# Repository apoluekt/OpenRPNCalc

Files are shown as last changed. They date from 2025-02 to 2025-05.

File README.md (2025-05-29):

# OpenRPNCalc
Open-source and open-hardware scientific RPN calculator

## Introduction

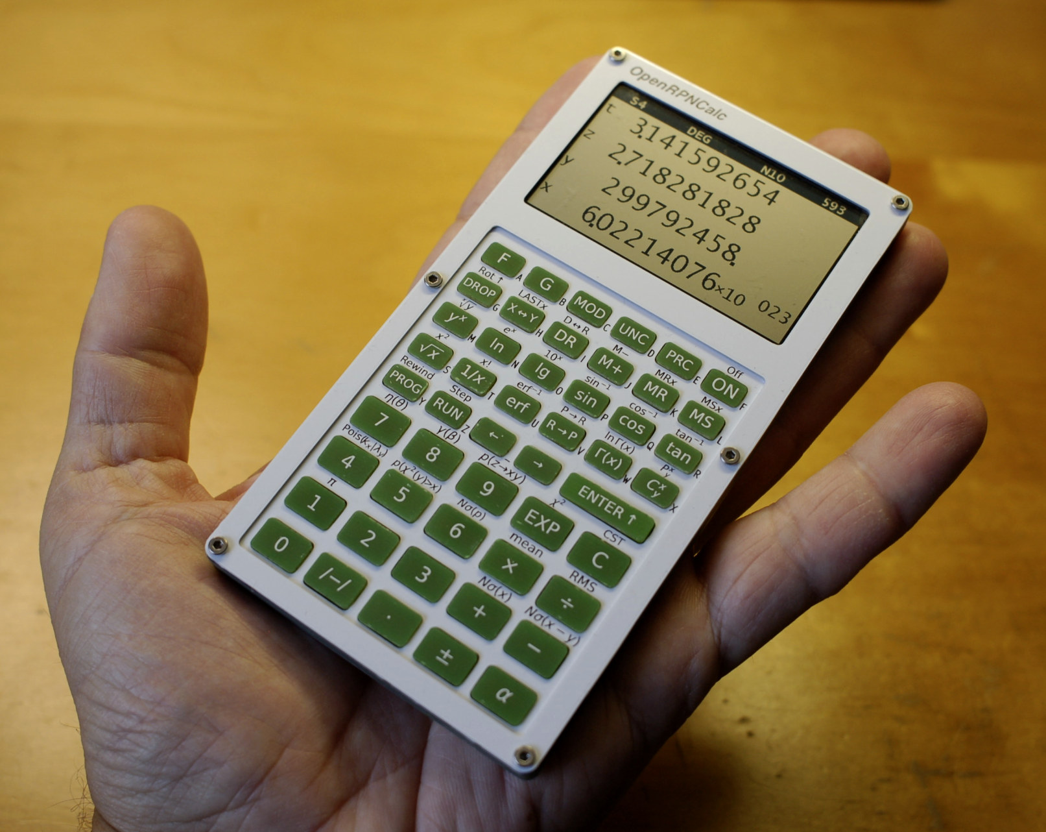
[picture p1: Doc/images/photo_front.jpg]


OpenRPNCalc is a scientific calculator based on the STM32 microcontroller. Its source code, schematics, and PCB design files are released under an open license. The goal is to develop a hardware platform with the following features: 
  * Reproducible without special tools, using only boards produced by PCB prototyping services
  * A customizable keyboard to accommodate specific needs (such as RPN or algebraic logic, custom functions)
  * Low power consumption and long battery life
  * A high-quality, compact and sturdy enclosure

The hardware is inspired by the [SwissMicros](https://www.swissmicros.com/products) calculators, but is designed from scratch. The calculator features: 

  * [Reverse Polish notation](https://www.hpmuseum.org/rpn.htm) with a large stack (up to 100 elements)
  * Double-precision arithmetic
  * "Standard" scientific calculator functions (trigonometric, logarithms, exponentiation, square root and power)
  * Error function (erf) and its inverse (erfinv), Gamma and log(Gamma) functions, combinations and permutations, p-values for Poisson, Gaussian, and chi-squared distributions
  * Fixed, scientific (SCI) and engineering (ENG) display modes (including SI prefixes in ENG mode), with adjustable precision from 3 to 10 digits
  * Calculations with uncertainties using error propagation (UNCERT mode) - a feature rarely found in software calculators and almost unheard of in hardware calculators
  * Formulas from relativistic kinematics (centre-of-mass two-body decay momentum, conversion between angle and pseudorapidity, beta and gamma factors)
  * Statistical functions: mean (or weighted mean in UNCERT mode), RMS, chi-squared of a series of values (only in UNCERT mode). 
  * 100 memory registers
  * Power consumption: 0.6mA running at 16MHz, 16 uA in standby mode with the LCD on, and 5 uA with the LCD off.
  * Optional HP48 keyboard files, with the aim to run [DB48x](https://48calc.org/) (this is still very much WIP)

## Hardware overview

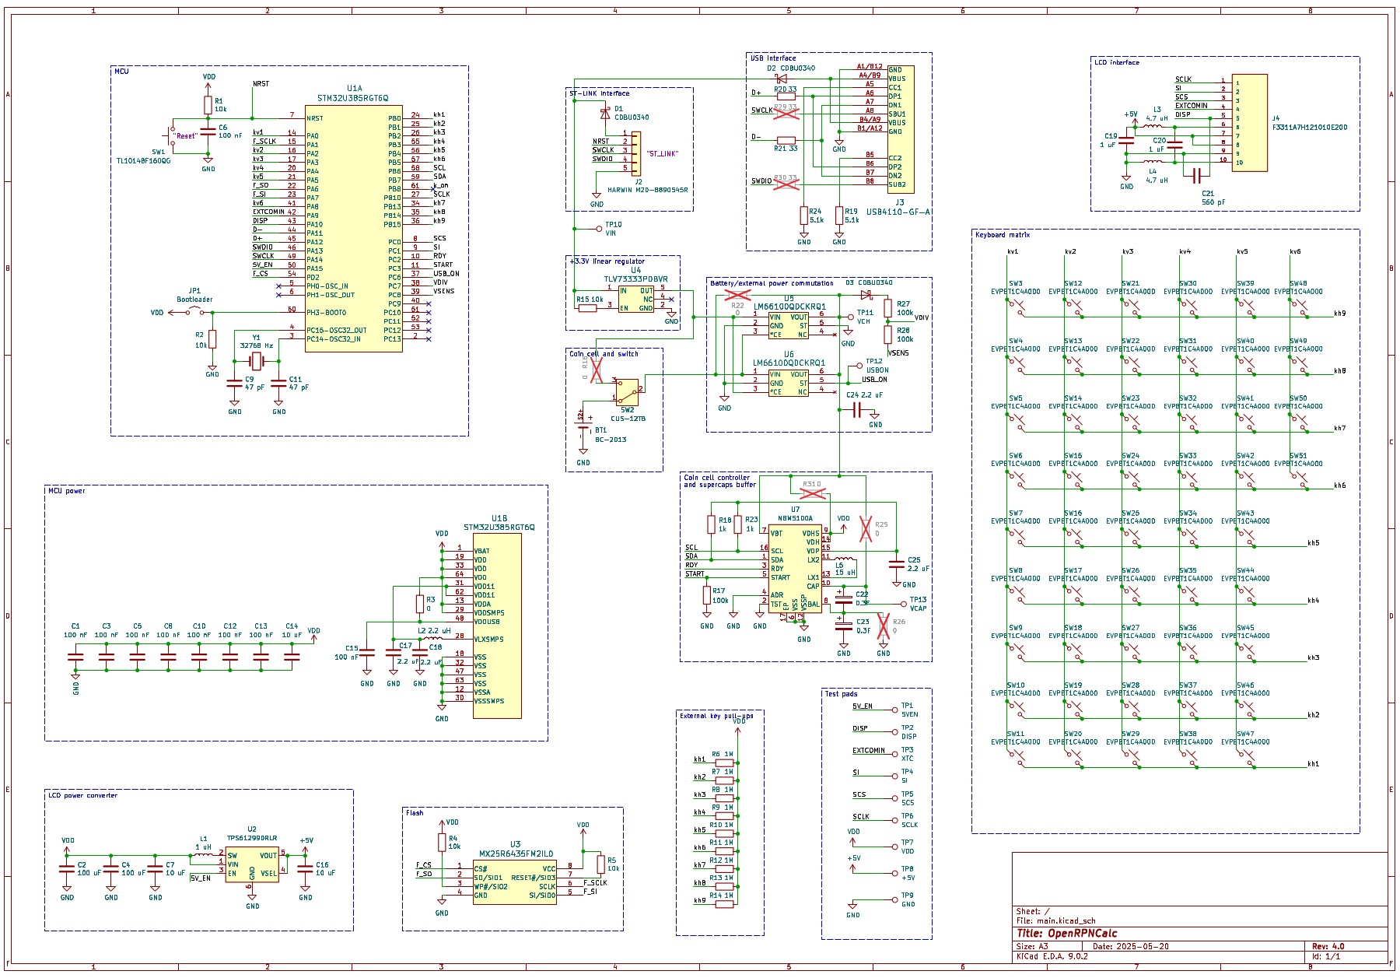
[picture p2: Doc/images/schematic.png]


The calculator is built around a low-power 32-bit ARM microcontroller, the [STM32U385](https://www.st.com/en/microcontrollers-microprocessors/stm32u385rg.html). The display is a Sharp memory LCD module, the [LS027B7DH01](https://www.sharpsde.com/products/displays/model/LS027B7DH01/) (400x240 pixel monochrome). The keyboard uses light-touch tactile switches, specifically the Panasonic [EVPBT1C4A000](https://industry.panasonic.com/global/en/products/control/switch/light-touch/number/evpbt1c4a000) (50g actuation force). All electronics are powered by a 3V lithium battery (CR2032), which should be sufficient for several years of operation. 

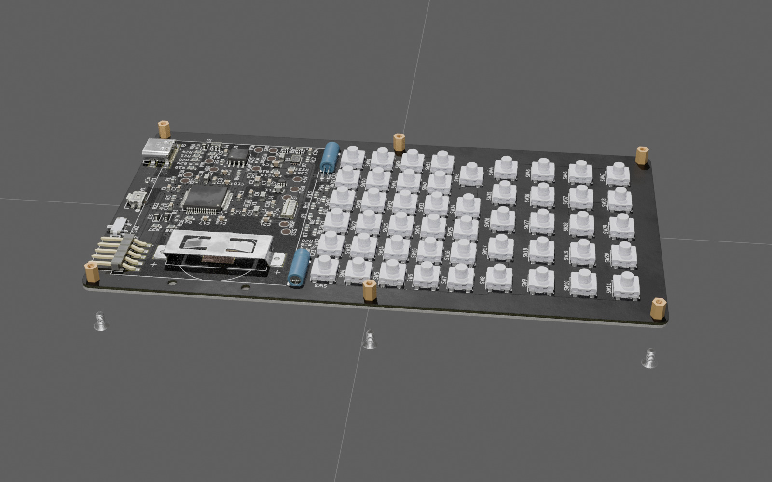
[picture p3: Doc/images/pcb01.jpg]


The enclosure is designed as a stack of multiple PCBs. The front and back panels are aluminium PCBs with a white solder mask and black silkscreen. The keys are also made of PCB, with labels printed as silkscreen. All components are kept together with six M2 standoffs and twelve flat-head screws. The enclosure dimensions are 139 x 73 x 8 mm. 

## Repository contents

   * [Code](Code): STM32 firmware developed using STM32Cube IDE
   * [Hardware](Hardware): Schematic and PCB design files for KiCad, PCB production files
   * [Doc](Doc): Documentation and images
   * [Emulator](Emulator): Online emulator files to be deployed to github-pages or other web hosting

## Documentation

   * [Schematics and parts](Doc/schematics.md) of the PCBs and the list of electronic components and other parts with links to datasheets
   * [PCB design](Doc/pcb_design.md): images of the PCB layers and their functions
   * [Case and keyboard assembly](Doc/assembly.md): photos of the insides of the calculator, assembly instructions
   * [Firmware](Code/README.md): code structure and flashing instructions

## Emulator 

[Online emulator](https://apoluekt.github.io/OpenRPNCalc/Emulator/), based on the original calculator firmware extended with Emscripten and Raylib

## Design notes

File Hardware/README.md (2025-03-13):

# Hardware design files

Contents of this folder: 

* [PCBs](PCBs): KiCad design files (schematic and PCBs) for all sevel layers. Where appropriate, Python files are also provided to produce silkscreen labels, place components, and make edge cuts.
* [production](production): Production files created in KiCad (Gerber files, bill of materials, position files for assembly service) for each of the 7 PCBs. These can normally be submitted to the PCB prototyping service without modifications.

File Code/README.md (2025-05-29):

# OpenRPNCalc firmware

The code is developed with STM32CubeIDE (specifically, version 1.17 under Linux). 

To create the binary file to flash the STM32 chip, go to "Project/Properties/C/C++ Build/Settings" and under "MCU/MPU Post build outputs" check "Convert to a binary file (-O binary)". Then build the project ("Project/Build all") which will produce the file "Debug/OpenRPNCalc.bin". This is the binary that needs to be flashed. 

STM32U3 series is not yet supported by the `st-link` tools in Linux. Use proprietary STM32CubeProgrammer.

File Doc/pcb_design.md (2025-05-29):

# PCB design

The enclosure is constructed as a stack of PCBs without needing 3D-printed elements.

Aluminium back panel and main PCB. All the PCBs are held together by six 4mm-high M2 brass standoffs. 



1st 1.6mm-thick spacer added. The standoffs need to be small enough to fit into 3.4mm holes in the spacers. The first spacer has guides to precisely position the keyboard switches while soldering. 

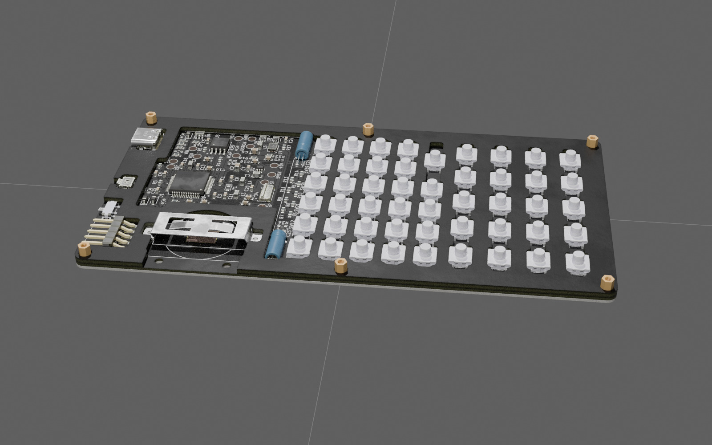
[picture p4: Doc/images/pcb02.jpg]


After adding the 2nd 1.6mm spacer. It covers most of the components on the main PCB and serves as a support for the LCD. 

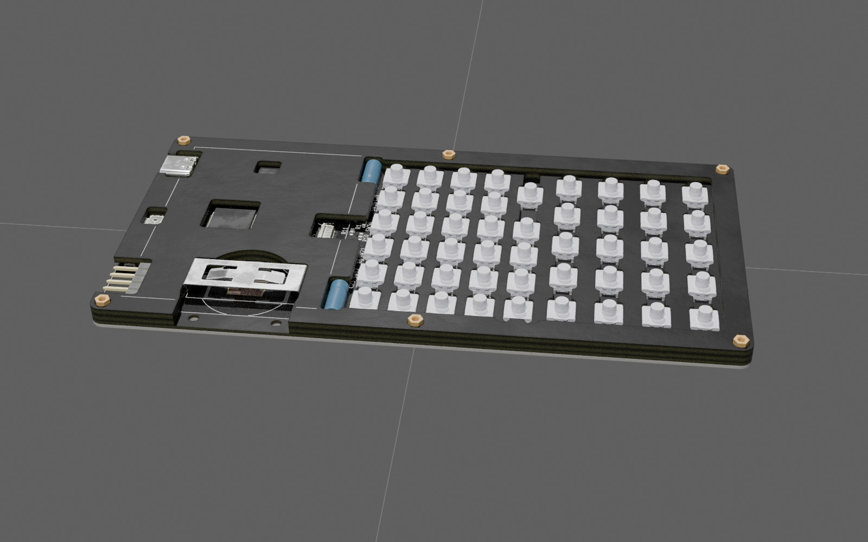
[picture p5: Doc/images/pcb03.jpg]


The CR2032 battery is installed in a slot that allows changing it without taking the full housing apart. The slot is made of two 1.6mm PCBs held by two M2 screws and nuts. To allow the slot to be inserted in the battery holder together with the battery, a wider bracket for the CR2430 battery is used instead of the CR2032 one. 

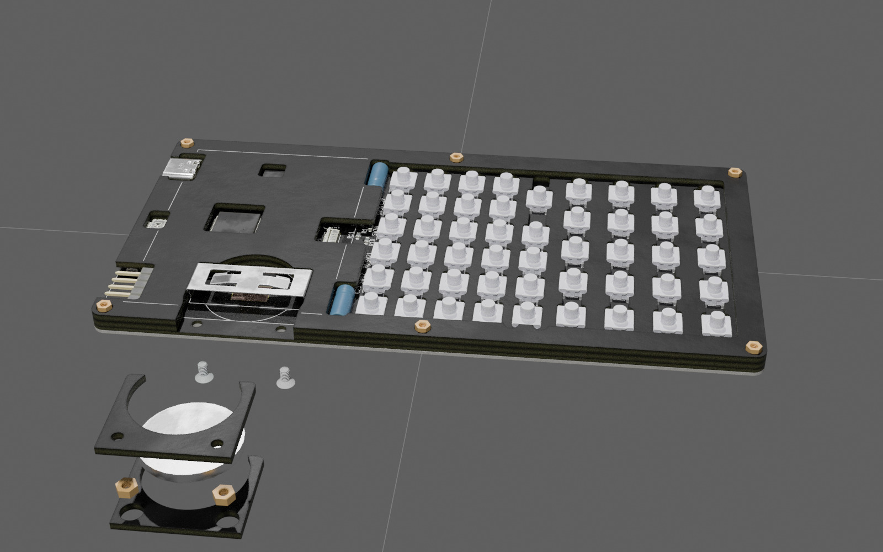
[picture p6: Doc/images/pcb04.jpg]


Battery slot installed in place. 

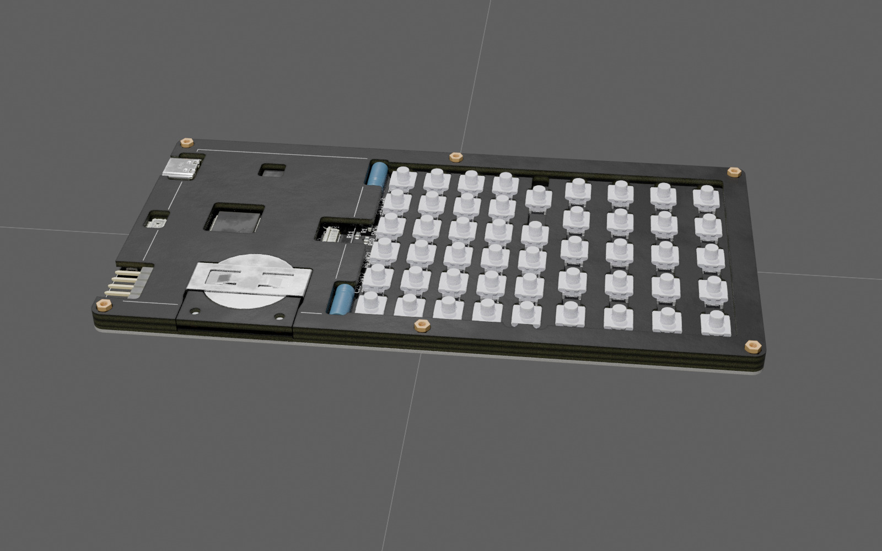
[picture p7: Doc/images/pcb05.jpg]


LCD connected. One needs to place an elastic (rubber) sheet of ~0.3mm thickness under the LCD such that it lies flat with the safe gap over the battery holder bracket. 

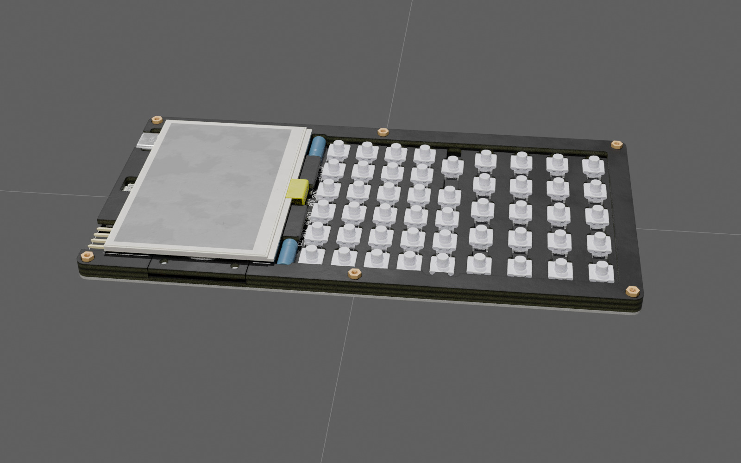
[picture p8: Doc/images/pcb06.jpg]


The 3rd 1.6mm spacer positions the LCD. 

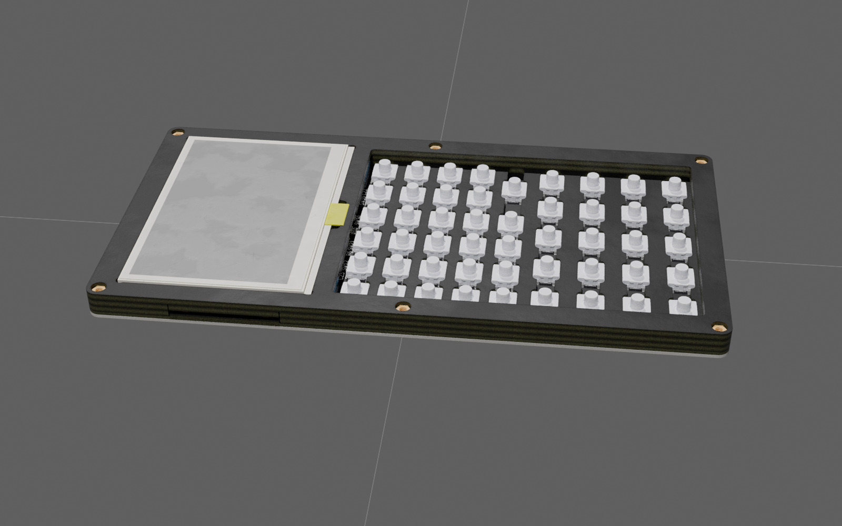
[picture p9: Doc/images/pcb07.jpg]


Keys are made of two parts soldered together: 1.6mm-thick top part with labels (with the solder pad on the bottom) and 0.8mm-thick bottom pad with plated through holes for soldering and 3mm diameter centre hole to put it tightly on the stem of the button switch. The wide "Enter" key has a thicker 1.2mm pad and a stabiliser that is hinged on the opposite side of the enclosure. 

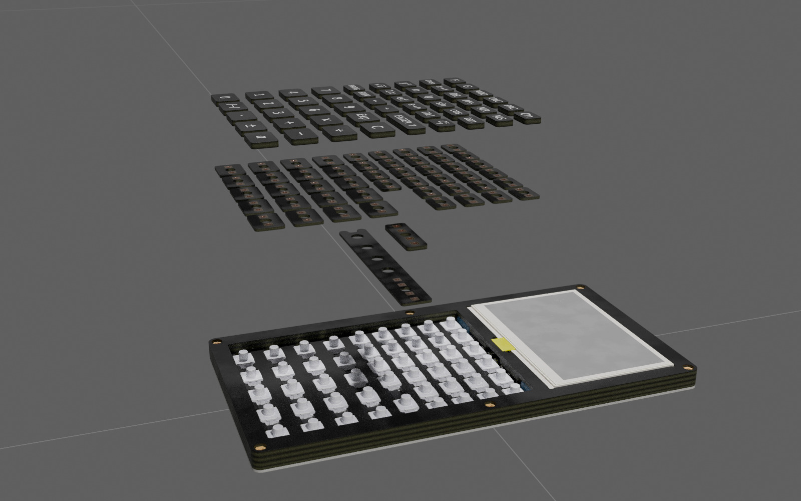
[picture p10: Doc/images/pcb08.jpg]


Wide "Enter" stabiliser and bottom pad put in place (in reality, it will also have the top part soldered at this stage). 

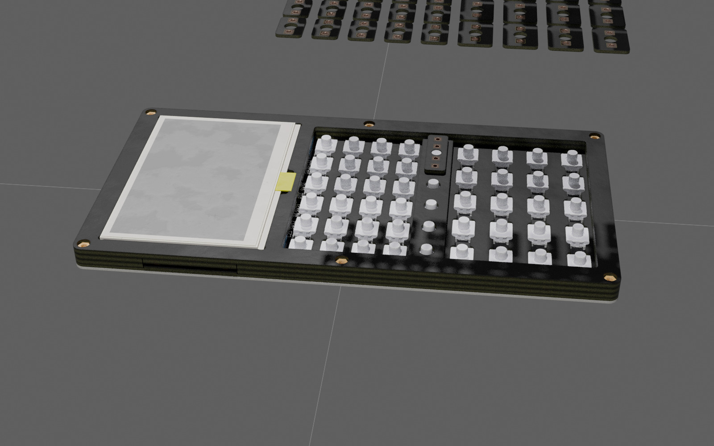
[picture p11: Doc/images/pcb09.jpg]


All keys put in place. 

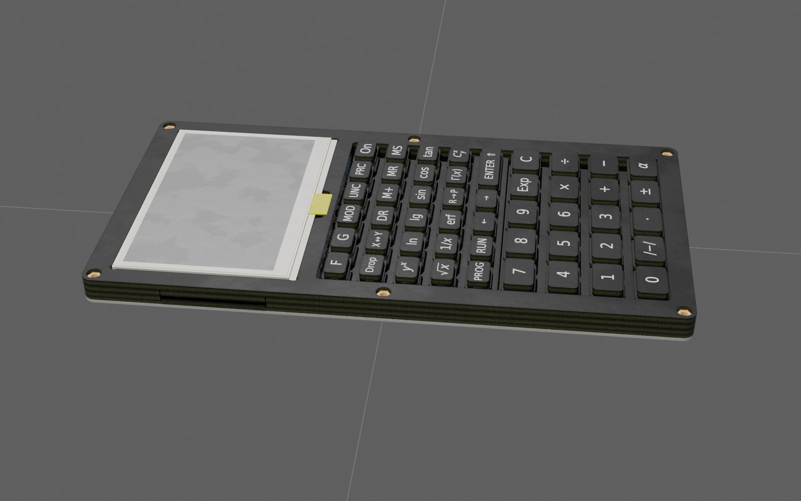
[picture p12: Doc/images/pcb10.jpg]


The front panel with labels and the frame that holds the LCD are held by six screws. 

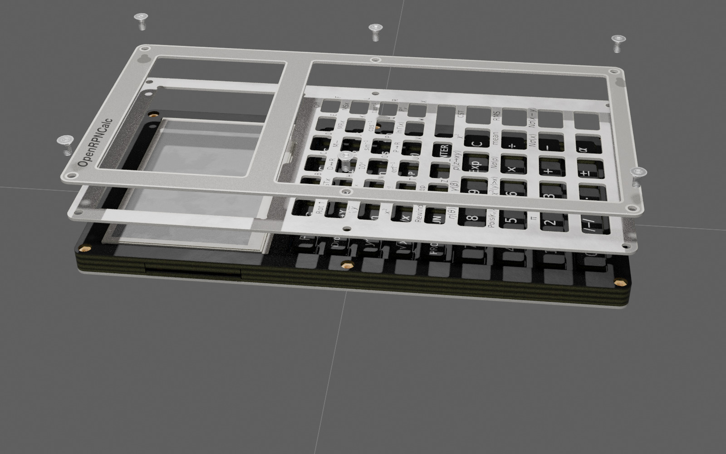
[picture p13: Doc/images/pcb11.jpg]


The calculator fully assembled. 

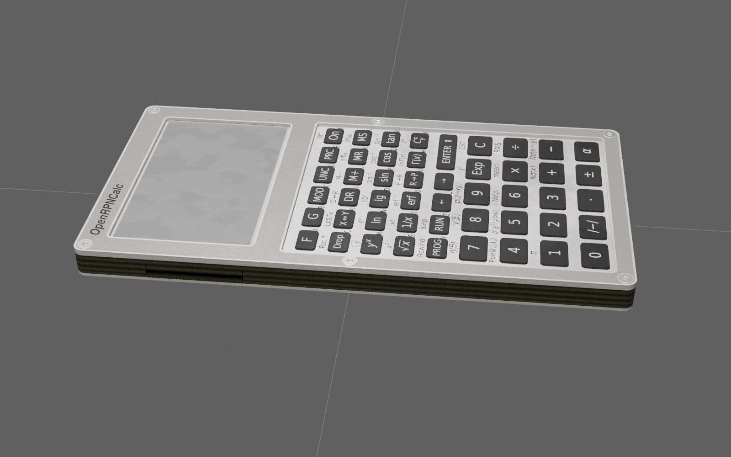
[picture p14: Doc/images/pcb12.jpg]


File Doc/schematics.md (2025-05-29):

# Schematics and parts

Rev. 4 uses a single PCB for the MCU and keyboard



## Notes 

### MCU

* The most recent STM32U385 is used here (256kB RAM, 1MB flash, ultra-low power with only 10 uA/MHz consumption)
* JP1 must be shorted to enter the USB bootloader for the fresh (or bricked) chip. 

### MCU power

* MCU is powered by the internal SMPS supply to ensure maximum power efficiency. The relevant external elements are L2, C17, and C18.
* R3, C15 are needed only if the USB interface is used. Otherwise, VDDUSB can be pulled to ground (?)

### LCD power converter

* This circuit is needed to provide +5V for the LCD. The newer TPS61299 chip is used with only 95 nA quiescent current. The version with "true shutdown" mode is used here (i.e. +5V rail is grounded when 5V_EN signal is low). 

### Flash

* Low-power 8MB chip Macronix MX25R6435FM2IL0 in single SPI mode (faster quad SPI mode is not used). 

### LCD interface

* Standard circuitry from LS027b7DH01 datasheet.
* Note that since the LCD connector is positioned on the PCB side facing the LCD, and the flat cable is bent 180 degrees, we have to use the flat cable connector that has contacts on **top**. The part used here has contacts on both sides, but the most abundant connectors with only bottom contacts won't work! 

### USB interface

* USB-C connector in USB-2.0 mode.
* SBU1 and SBU2 contacts can optionally be connected to the ST-LINK interface lines by installing the bridges R29 and R30 (not populated by default). This should allow for using the [SWD over USB-C](https://hackaday.io/project/192857-swd-over-usb-type-c-new-way-of-programming-boards) programmer and debugger. 

### ST-LINK interface

* 2.5mm pitch connector. Can use either 5V or 3.3V (?) lines from the ST-LINK probe to power the calculator. 

### +3.3V linear regulator

* Simple LDO regulator that produces stabilised +3.3V from either USB or ST-LINK input.

### Coin cell and switch

* The power switch is installed to completely switch the power off without removing the battery. Normally, the MCU is always in the idle (STOP) mode waiting for the external interrupt, so operating the switch in normal operation is not needed. 

### Battery/external power commutation

* A pair of "ideal diodes" which take the power from the source with a higher voltage. The USB_ON signal tells the MCU that external power is connected.
* U5 and U6 are optional. Instead, one can install the bridges R22 and R16 to manually switch the power between the battery and external (USB/ST-LINK) sources. 
* D3, R27 and R28 make a switchable divider to measure the battery voltage when VSENS is pulled low. When VSENS is disconnected (most of the time), there is no current drain. One has to make sure that the MCU is operated at the voltage (VDD) not lower than the battery voltage, otherwise the current will flow via the internal protection diodes in the MCU. 

### Coin cell controller and supercaps buffer

* NBM5100A is the coin cell life booster with supercap buffer. It limits the maximal current drawn from the coin cell to a programmable value (can be as low as 2 mA), with the excess taken from the supercaps during periods of high power consumption. It also provides stabilised voltage to power the STM32 and other circuitry.
* NBM5100A is optional. Instead of installing it, together with the surrounding passive elements, one can install the brige R31 to directly connect the calculator circuit to the coin cell or external power. Possibly, one can also install one of the supercaps and add the bridge R26 (not two supercaps sequentially, due to the absence of balancing). Make sure the supercap can survive 3.3V input voltage in this case. 
* Output voltage for NBM5100A should be set to 3V to make sure that the switchable voltage divider (see above) works correctly. 

### External pull-ups

* 1M pull-ups are used instead of STM32 internal 40k pull-ups to limit the current draw when the keys are pressed.
* It seems that the input pin capacitance and parasitic capacitance of the keyboard traces are high enough that a quick scan of the keyboard matrix is impossible with such high-impedance pull-ups. Therefore, the firmware should use them only when waiting for an external interrupt in the idle mode (waiting for a key press event), but to do the keyboard scan to determine which key was pressed, one has to switch the internal pull-ups in addition. 

### Test pads

* LCD signals and voltages 

### Keyboard matrix

* No diodes are added, so only up to two simultaneous key presses can be registered without ghosting. 

## Parts and datasheets

Electronic components from the KiCAD BOM: 

| Quantity | Value/model | Package | Comment |
|-|-|-|-|
| 1	| [STM32U385RGT6Q](https://www.st.com/en/microcontrollers-microprocessors/stm32u385rg.html) | LQFP64 | Microcontroller | 
| 1	| [MX25R6435FM2IL0](https://www.macronix.com/Lists/Datasheet/Attachments/8868/MX25R6435F,%20Wide%20Range,%2064Mb,%20v1.6.pdf)	| SOP-8L | 8MB flash memory | 
| 1	| [Nexperia NBM5100A](https://www.nexperia.com/product/NBM5100ABQ) | DHVQFN-16 | Coin cell controller | 
| 1	| [TI TPS61299](https://www.ti.com/product/TPS61299)	| SOT-5X3 (DRL) | 5V step-up converter | 
| 1	| [TI TLV73333PDBVR](https://www.ti.com/product/TLV733P/part-details/TLV73333PDBVR) | SOT-23 (DBV0005A) | LDO voltage regulator | 
| 2	| [TI LM66100QDCKRQ1](https://www.ti.com/product/LM66100-Q1/part-details/LM66100QDCKRQ1) | SOT-SC70 (DCK0006A) | Ideal diode | 
| 1	| [TL1014BF160QG](https://www.e-switch.com/wp-content/uploads/2022/06/TL1014.pdf) | | Button switch |
| 49 | [Panasonic EVPBT1C4A000](https://industry.panasonic.com/global/en/products/control/switch/light-touch/number/evpbt1c4a000)	| | Button switch |
| 1	| [Nidec CUS-12TB](https://www.nidec-components.com/us/product/detail/00000195/) | | Slide switch | 
| 1	| [BC-2013](https://www.batteryholders.com/part.php?pn=BC-2013&original=&override=)	| | CR2430 coin cell battery holder |
| 1	| [HARWIN M20-8890545R](https://www.harwin.com/products/M20-8890545R) | | SMT pin header, 5 pins, 2.5mm pitch |
| 1	| [USB4110GFA](https://gct.co/connector/usb4110) | | USB-C connector | 
| 1	| [AMPHENOL F3311A7H121010E200](https://www.amphenol-cs.com/product/f3311a7h121010e200.html) | | Flat cable connector, 10 pins, 0.5mm pitch, top and bottom contacts | 
| 1	| 32768 Hz | 2012 | Quartz resonator | 
| 3	| CDBU0340	| 0603 | Schottky diode | 
| 1	| 1 uH | 0805 | Inductor | 
| 1	| 2.2 uH | 0805 | Inductor | 
| 2	| 4.7 uH | 0805 | Inductor | 
| 1	| 15 uH	| 0805 | Inductor | 
| 9	| 100 nF	| 0603 | Ceramic capacitor |
| 2	| 47 pF	| 0603 | Ceramic capacitor |
| 3	| 10 uF	| 0603 | Ceramic capacitor |
| 4	| 2.2 uF | 0603 | Ceramic capacitor |
| 2	| 1 uF | 0603 | Ceramic capacitor |
|	2 | 100 uF | 0805 | Ceramic capacitor |
| 1	| 560 pF | 0603 | Ceramic capacitor |
| 2	| 0.3F | 4x10mm | Supercapacitor | 
| 5	| 10k	| 0603 | Resistor | 
| 9	| 1M | 0603 | Resistor | 
| 3	| 100k | 0603 | Resistor | 
| 2	| 1k | 0603 | Resistor |
| 2	| 5.1k | 0603 | Resistor |
| 2	| 33 | 0603 | Resistor |
| 1	| 0	| 0603 | Resistor |

Other components

| Quantity | Part |  
| - | - |
| 1 | Sharp Memory LCD, model [LS027B7DH01](https://www.alldatasheet.com/datasheet-pdf/pdf/433405/SHARP/LS027B7DH01.html) |
| 1 | CR2032 coin cell battery | 
| 6 | M2 x 4mm brass standoff, Round or hex, should tightly fit into 3.4mm holes on the PCB | 
| 14 | M2 x 4mm screw | 
| 4-5 | M3 screw and nut for the keycap soldering jig | 
| 2 | M2 x 1.6mm hex nut |
| 1 | ST-LINK v2 programmer with 2.5mm pitch pin header cable | 
| 1 | USB-C cable |

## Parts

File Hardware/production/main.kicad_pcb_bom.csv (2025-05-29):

Designator | Quantity | Value | Footprint | Package | MPN | DNP | Mount_Type | PARTREV | STANDARD | MAXIMUM_PACKAGE_HEIGHT | MANUFACTURER | Description | Function
BT1 | 1 | BC-2013 | BAT_BC-2013 |  |  |  | smt | D | Manufacturer Recommendations | 2.28mm | MPD
C1, C10, C12, C13, C15, C3, C5, C6, C8 | 9 | 100 nF | C_0603_1608Metric_Pad1.08x0.95mm_HandSolder |  |  |  | smt |  |  |  |  | Unpolarized capacitor
C11, C9 | 2 | 47 pF | C_0603_1608Metric_Pad1.08x0.95mm_HandSolder |  |  |  | smt
C14, C16, C7 | 3 | 10 uF | C_0603_1608Metric_Pad1.08x0.95mm_HandSolder |  |  |  | smt
C17, C18, C24, C25 | 4 | 2.2 uF | C_0603_1608Metric_Pad1.08x0.95mm_HandSolder |  |  |  | smt |  |  |  |  | Unpolarized capacitor
C19, C20 | 2 | 1 uF | C_0603_1608Metric_Pad1.08x0.95mm_HandSolder |  |  |  | smt
C2, C4 | 2 | 100 uF | C_0805_2012Metric_Pad1.18x1.45mm_HandSolder |  |  |  | smt
C21 | 1 | 560 pF | C_0603_1608Metric_Pad1.08x0.95mm_HandSolder |  |  |  | smt
C22, C23 | 2 | 0.3F | Supercap_4x10 |  |  |  | smt |  |  |  |  | Polarized capacitor
D1, D2, D3 | 3 | NSR0340HT1G | D_0603_1608Metric_Pad1.05x0.95mm_HandSolder |  |  |  | smt
J2 | 1 | HARWIN M20-8890545R | HARWIN_M20-8890545R |  |  |  | smt |  |  |  |  |  | "ST_LINK"
J3 | 1 | USB4110-GF-A | GCT_USB4110GFA |  |  |  | smt
J4 | 1 | F3311A7H121010E200 | AMPHENOL_F3311A7H121010E200 |  |  |  | smt | A | Manufacturer Recommendations | 1.62 mm | Amphenol
JP1 | 1 | Bootloader | R_0603_1608Metric_Pad0.98x0.95mm_HandSolder |  |  |  | smt |  |  |  |  | Jumper, 2-pole, open
L1 | 1 | 1 uH | L_0805_2012Metric_Pad1.15x1.40mm_HandSolder |  |  |  | smt
L2 | 1 | 2.2 uH | L_0805_2012Metric_Pad1.05x1.20mm_HandSolder |  |  |  | smt |  |  |  |  | Inductor
L3, L4 | 2 | 4.7 uH | L_0805_2012Metric_Pad1.15x1.40mm_HandSolder |  |  |  | smt
L5 | 1 | 15 uH | L_0805_2012Metric_Pad1.05x1.20mm_HandSolder |  |  |  | smt |  |  |  |  | Inductor
R1, R15, R2, R4, R5 | 5 | 10k | R_0603_1608Metric_Pad0.98x0.95mm_HandSolder |  |  |  | smt
R10, R11, R12, R13, R14, R6, R7, R8, R9 | 9 | 1M | R_0603_1608Metric_Pad0.98x0.95mm_HandSolder |  |  |  | smt
R17, R27, R28 | 3 | 100k | R_0603_1608Metric_Pad0.98x0.95mm_HandSolder |  |  |  | smt |  |  |  |  | Resistor
R18, R23 | 2 | 1k | R_0603_1608Metric_Pad0.98x0.95mm_HandSolder |  |  |  | smt |  |  |  |  | Resistor
R19, R24 | 2 | 5.1k | R_0603_1608Metric_Pad0.98x0.95mm_HandSolder |  |  |  | smt |  |  |  |  | Resistor
R20, R21 | 2 | 33 | R_0603_1608Metric_Pad0.98x0.95mm_HandSolder |  |  |  | smt |  |  |  |  | Resistor
R3 | 1 | 0 | R_0603_1608Metric_Pad0.98x0.95mm_HandSolder |  |  |  | smt |  |  |  |  | Resistor
SW1 | 1 | TL1014BF160QG | TL1014BF160QG_EWI |  |  |  | smt |  |  |  |  |  | "Reset"
SW10, SW11, SW12, SW13, SW14, SW15, SW16, SW17, SW18, SW19, SW20, SW21, SW22, SW23, SW24, SW25, SW26, SW27, SW28, SW29, SW3, SW30, SW31, SW32, SW33, SW34, SW35, SW36, SW37, SW38, SW39, SW4, SW40, SW41, SW42, SW43, SW44, SW45, SW46, SW47, SW48, SW49, SW5, SW50, SW51, SW6, SW7, SW8, SW9 | 49 | EVPBT1C4A000 | SW_SPST_EVQQ2 |  |  |  | smt
SW2 | 1 | CUS-12TB | CUS-12TB_NDC |  |  |  | smt
TP1 | 1 | 5VEN | TestPoint_Pad_D2.0mm |  |  |  | tht
TP10 | 1 | VIN | TestPoint_Pad_D2.0mm |  |  |  | tht
TP11 | 1 | VCH | TestPoint_Pad_D2.0mm |  |  |  | tht
TP12 | 1 | USBON | TestPoint_Pad_D2.0mm |  |  |  | tht
TP13 | 1 | VCAP | TestPoint_Pad_D2.0mm |  |  |  | tht
TP2 | 1 | DISP | TestPoint_Pad_D2.0mm |  |  |  | tht
TP3 | 1 | XTC | TestPoint_Pad_D2.0mm |  |  |  | tht
TP4 | 1 | SI | TestPoint_Pad_D2.0mm |  |  |  | tht
TP5 | 1 | SCS | TestPoint_Pad_D2.0mm |  |  |  | tht
TP6 | 1 | SCLK | TestPoint_Pad_D2.0mm |  |  |  | tht
TP7 | 1 | VDD | TestPoint_Pad_D2.0mm |  |  |  | tht
TP8 | 1 | +5V | TestPoint_Pad_D2.0mm |  |  |  | tht
TP9 | 1 | GND | TestPoint_Pad_D2.0mm |  |  |  | tht
U1 | 1 | STM32U385RGT6Q | LQFP64_STM |  |  |  | smt
U2 | 1 | TPS61299DRLR | SOT-563 |  |  |  | smt
U3 | 1 | MX25R6435FM2IL0 | SOP_8L_200_MAC |  |  |  | smt
U4 | 1 | TLV73333PDBVR | DBV0005A_N |  |  |  | smt
U5, U6 | 2 | LM66100QDCKRQ1 | SC70-6_DCK_TEX |  |  |  | smt
U7 | 1 | NBM5100A | DHVQFN-16-1EP_2.5x3.5mm_P0.5mm_EP1x2mm |  |  |  | smt |  |  |  |  | coin cell booster charge pump DHVQFN16 SOT763
Y1 | 1 | 32768 Hz | Crystal_SMD_2012-2Pin_2.0x1.2mm_HandSoldering |  |  |  | smt

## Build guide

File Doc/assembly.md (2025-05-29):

# Assembly

PCBs as they come from the prototyping service. The white ones are aluminium-based (black silkscreen on white mask), and the others are the usual FR4 (white silkscreen on black mask or green mask in the case of keycaps). 
The Alu PCBs are used as they are, while the FR4 PCBs contain panelised keycaps (the green board), parts of the jig to help solder the keys (denoted A, B, and C) and battery slot layers (3rd PCB in the top row) that have to be separated from the frames before assembling the enclosure. 

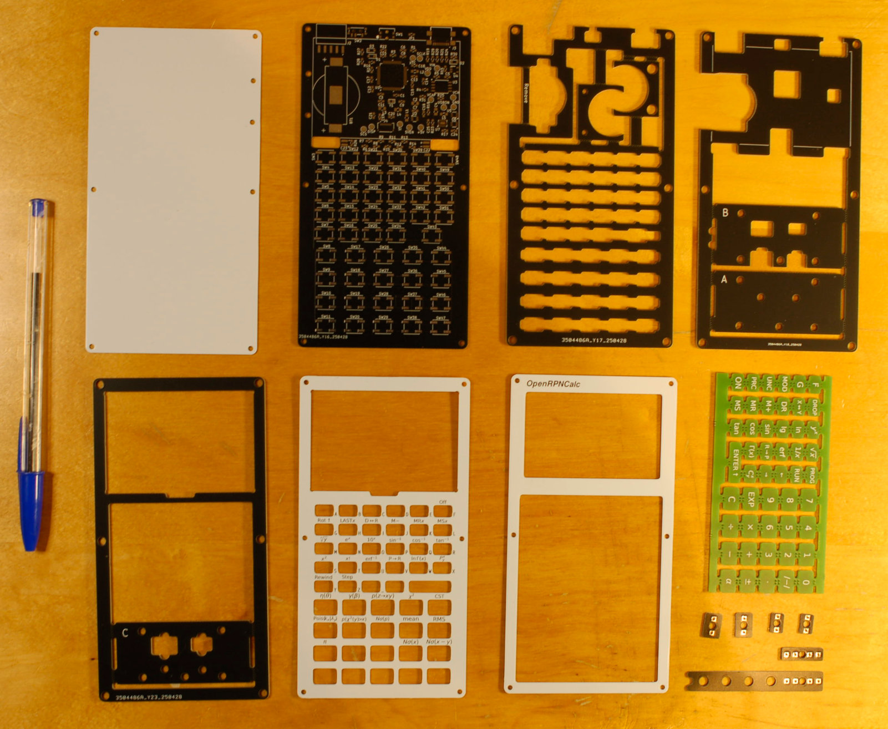
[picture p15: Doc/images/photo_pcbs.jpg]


The soldering jig assembled. It's made as a stack of three 1.6mm-thick boards (denoted from bottom to top A, B, and C) kept together with M3 screws and nuts. The two slots on the edge are used to hold the top parts of the keycaps while finishing them with the file to remove "mouse bites" traces, while the two slots on the top side are used to precisely position the top and the bottom parts of the keycap while soldering them together. 

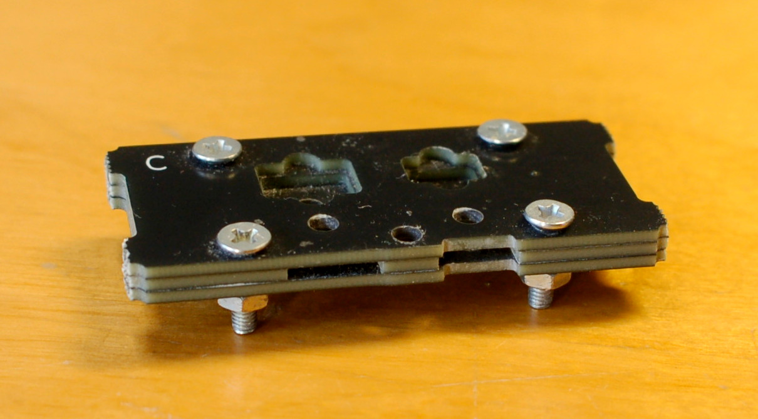
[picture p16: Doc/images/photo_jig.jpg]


Soldered keycaps after cleaning with isopropanol. 

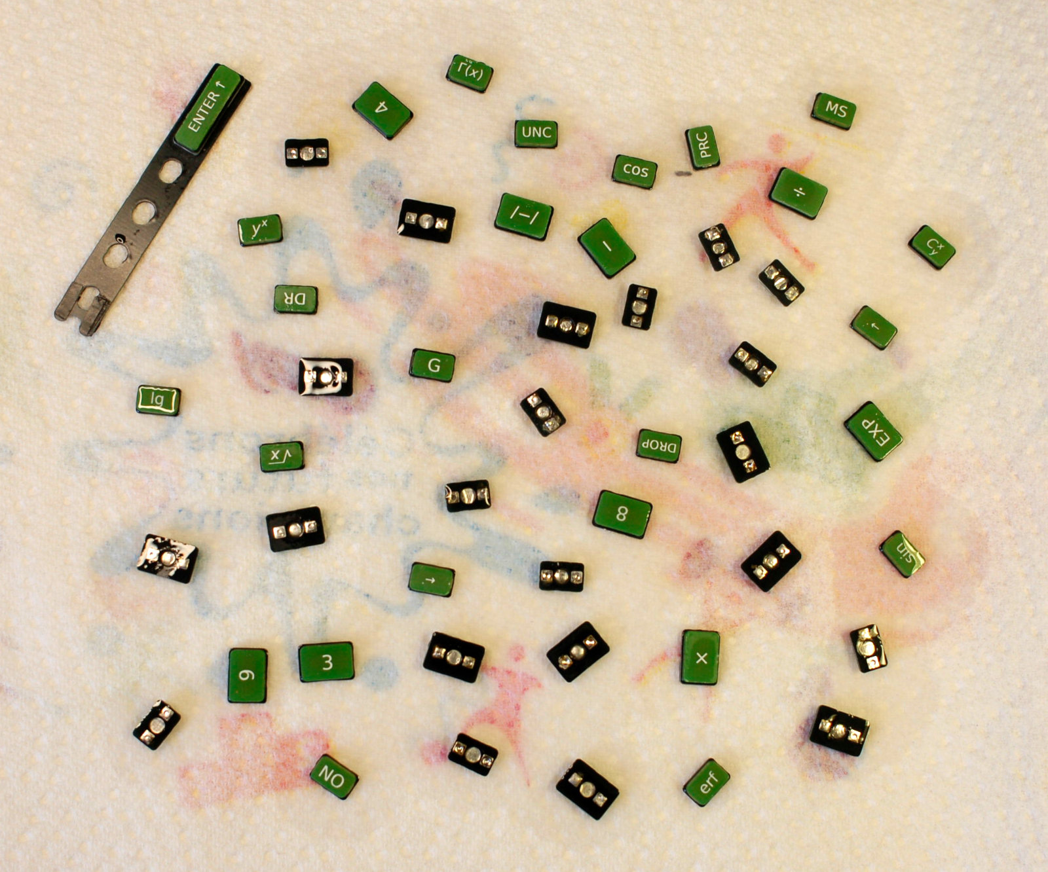
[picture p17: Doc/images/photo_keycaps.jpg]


The main PCB (without soldering the electronic components) with Spacer 1 on top, battery holder and slot with the CR2032 battery, Enter key with its stabiliser and a couple of other keys. 

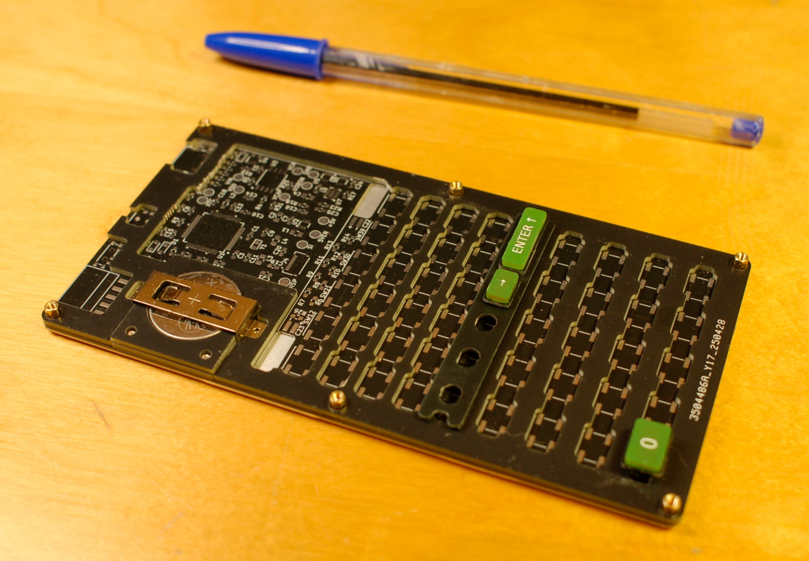
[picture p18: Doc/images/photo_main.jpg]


The main PCB with components soldered and Spacer 1 placed on top. The spacer has "rails" to precisely position the button switches for manual soldering. 

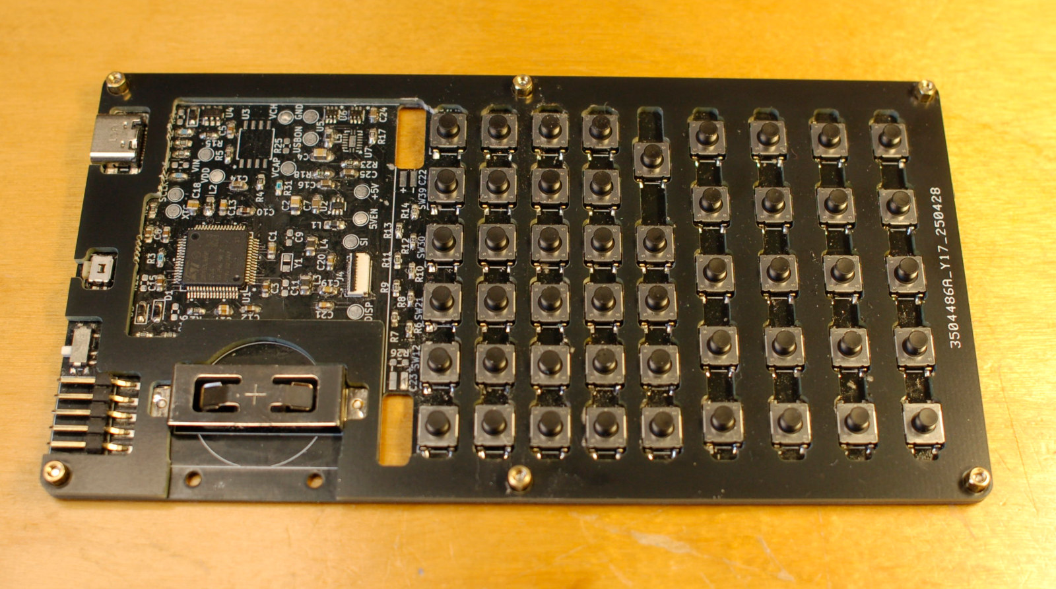
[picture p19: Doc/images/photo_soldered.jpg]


Closeup view of the (from left to right) USB-C connector, Reset switch, power switch and ST-LINK connector. 

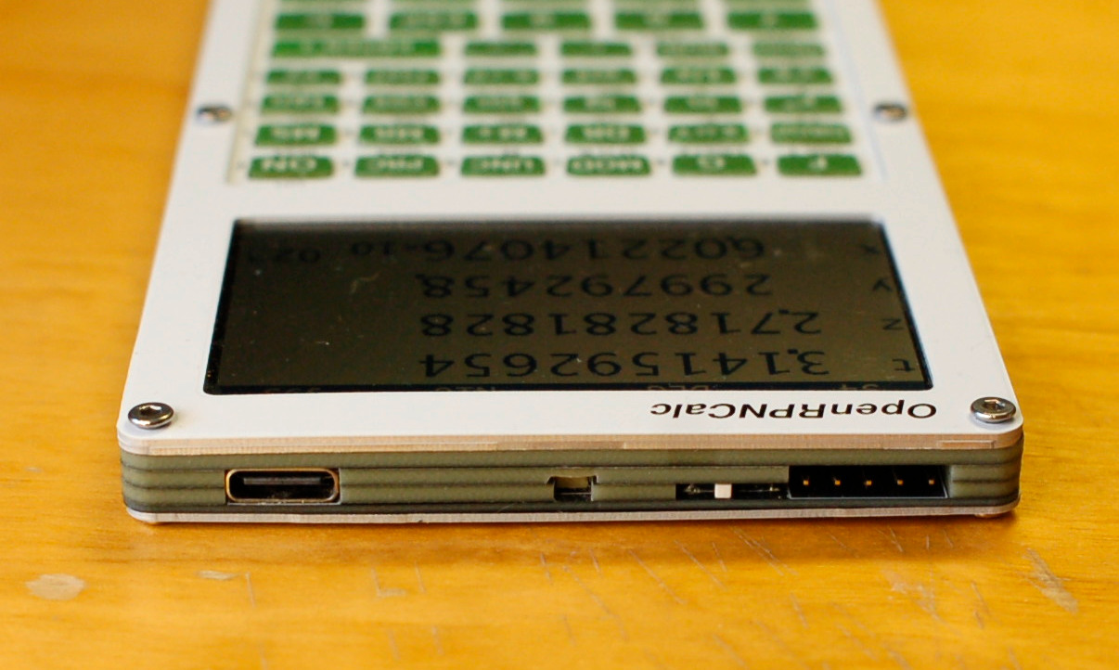
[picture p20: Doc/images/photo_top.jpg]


Fully assembled calculator 



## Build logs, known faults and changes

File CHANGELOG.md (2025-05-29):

# Changelog

## 29/05/2025 
  * Updated firmware to be used with STM32U385 MCU. For now, minimal changes wrt. rev3.1:
    * Remap keys to the new 49-key layout
    * Update pinout to the new hardware
    * Small updates related to the modifications in HAL (EXTI callbacks)
    * Battery voltage measurement still has issues, showing raw ADC reading instead of volts. 

## 20/05/2025.
  * Bug fixes to Rev 4: 
    * Spacer2: Adjusted key soldering jig; increased gap between the battery holder and the spacer
    * EnterStab: Adjusted hole positions
    * Main: Corrected footprints for TPS61299 and diodes
  * Added HP48 keyboard layout in addition to the custom one: 
    * PCBs in Hardware/PCBs with _hp48 suffix
    * production files in Hardware/production with _hp48 suffix

## 27/04/2025. Revision 4
  * Hardware modifications in Rev 4:
    * [STM32U385](https://www.st.com/en/microcontrollers-microprocessors/stm32u385rg.html) processor
    * Added USB interface (USB-C connector) with optional support of [SWD over USB-C](https://hackaday.io/project/192857-swd-over-usb-type-c-new-way-of-programming-boards)
    * Added external flash ([Macronix MX25R6435F](https://www.macronix.com/Lists/Datasheet/Attachments/8868/MX25R6435F,%20Wide%20Range,%2064Mb,%20v1.6.pdf), 8Mbytes)
    * Added coin cell booster with supercaps buffer ([Nexperia NBM5100A](https://www.nexperia.com/product/NBM5100ABQ) and 2x0.3F caps)
    * New 5V booster for LCD ([TPS61299](https://www.ti.com/product/TPS61299))
    * External/battery voltage commutation with a pair of "ideal diodes" ([LM66100-Q1](https://www.ti.com/product/LM66100-Q1))
    * Keyboard layout modifications: additional row of function keys, wide "Enter"
    * Different model of tactile switches (Panasonic EVP-BT1C4A000) to avoid 3D-printed pads for the keys
    * CR2032 coin cell by default

## 28/03/2025
  * Firmware: 
    * Rudimentary programming capability: record up to 100 operations and run the recorded sequence either all at once or step-by-step. 
      No loops or branching.
    * Increase delays in keyboard scan for stability with high-impedance pull-ups
    * Speed up LCD output
    * Independent setting of precision (number of significant digits) for NORMAL and UNCERT contexts
  * Hardware: 
    * Updated front panel labels to reflect the firmware update (added programming functions).

## 07/03/2025
  * Hardware: Rev. 3 of the schematics and enclosure. 
  * Firmware:
    * 100 memory registers accessible via F-RCL and F-STO functions, with the address of the memory register passed in the X register of the stack
    * Changes for Rev. 3 of hardware (upright LCD screen instead of upside-down in the old revisions; external pull-ups for key matrix)
    * Enscripten/raylib code for the online emulator

## 20/02/2025
  * "Infinite" stack (HP48-like) instead of the fixed 4-element one (HP42-like). Practically, it's now limited to 100 elements,
    outght to be enough for anybody, and can be extended. 
  * Statistical functions (chi2 and mean for now) work with all the elements of the stack. 
  * Small bug fixes in the stack behaviour. 

## 14/02/2025 
  * New functions: 
    - Chi2, mean and RMS of values in the stack with uncertainties (work only in UNCERT) mode
    - Factorial
  * Keyboard scan fully interrupt-driven (entering STOP even when waiting for key release) and a few bugfixes 
    to improve keyboard response

## 01/01/2025
  * Working on Rev. 2 of OpenRPNCalc. Changes in firmware, enclosure and PCB design, mostly the same schematics. 
  * Changes in firmware:
    - Improvements in the alignment of the display elements and status bar.
    - Added cursor to highlight input elements (value or uncertainty, mantissa or exponent).
    - Removed the unnecessary delay loop in the initialisation phase.
  * Major change in the enclosure design:
    - The idea is to make an enclosure as a sandwich of PCBs rather than the 3d-printed one
    - More reliable silkscreen labels instead of printed stickers
    - Keyboard with PCB-based keys and pin header "pivots" (preliminary design for now, waiting for the PCBs to arrive)

## 25/06/2021
  * Added ROT-Up and ROT-Down functions ("F"+"Drop" and "G"+"Drop"): stack rotation in two directions
  * Added uncertainties for Y^X and ROOT(Y, X) functions

## 21/06/2021 
  * Added Poisson PDF ("F"+"4") and chi-squared tail probability ("F"+"5") functions

## 19/06/2021
  * Small fixes in schematics to reflect what is actually implemented in hardware. 
  * Put STM32 to STOP2 mode instead of STOP1 during standby. This reduces the current 
    consumed from battery to 2-3 uA with LCD off and 10-12 uA with LCD on
    (was 40 and 55 uA, respectively, with STOP1). 
  * Add new photos of the keyboard. 
  * Add links to datasheets in Doc/schematics.md

## 02/06/2021
  * Added C(n,k), P(n,k) functions calculated using log(Gamma) formula. 
    No check is done that arguments are positive, integer, etc.
  * Added significance (Nsigma(x), Nsigma(x-y)) functions. Work only in 
    UNCERT context. 

## 28/05/2021
  * Added relativistic kinematics functions (uncertainties are not implemented yet for them): 
    * Conversion between angle and pseudorapidity (eta <-> theta)
    * Conversion between beta and gamma factors (gamma <-> beta)
    * Center-of-mass momentum for 2-body decay (P(z->xy))
  * Gamma and log Gamma functions. 
  * Conversion between degrees and radians. 
  * Slight reshuffle of function keys. 
  * Update with ST-Link is now activated with "SHIFT+Reset" (instead of "ON+Reset").

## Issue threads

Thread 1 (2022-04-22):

Best calculator ever!

BasilioPV, 2022-04-22:
Thanks for sharing this awesome project to the community. I always dreamed with a calculator with the power of an Casio FX 991 but with the size of 80's Casio pocket models (which includes a plastic wallet and fit in the shirt pocket).

This project open the eyes for me: small size and simple electronics, ultra low power consumption (can be powered by solar cell) and very powerful.

I have some questions for you:
How do you produce the PCB including soldering components?
How can I purchase all components?

BasilioPV, 2025-03-17:
What PCB prototyping service do you use? Thanks very much for this project!

apoluekt, 2025-03-17:
Any cheap service that is able to do single-sided Alu PCBs and 0.8mm FR4. I've used JLCPCB, but see the caveat [here](https://www.hpmuseum.org/forum/thread-23291-post-201204.html#pid201204). For the PCB with the labels, you might want to use the service with a more transparent pricing policy, such as Aisler.

randy197, 2025-06-05:
Thanks @jcard0na , sorry I missed this in the discussions.

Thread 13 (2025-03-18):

LCD Availability

randy197, 2025-03-18:
Hi Anton, this project made my day when I found it. I immediately started collecting the BOM but have found the Sharp LCD you have used is VERY hard to come by from official sources.

Are there plans to use a different LCD in future? Or do you have any alternative suggestions? I have placed an order for a AliExpress 'version'. Will see how good the quality is. An AliExpress reviewer noted his LCD had a much higher power consumption compared to the genuine.

apoluekt, 2025-03-18:
Indeed, finding the Sharp screen is annoyingly hard, and your best bet is to go to AliExpress. It seems the cheapest sellers may sell the screens that are faulty in some way, so I'd try the more reputable ones.

The problem is any other LCD available at e.g. DigiKey is a sort of compromise in terms of quality, thickness, etc. I'd need to investigate, but a few years ago there really was no other option. If you find something competitive, let me know.

randy197, 2025-03-18:
Thanks for the reply. When it arrives I'll post back here on the quality. Could potentially start a catalogue of sellers which have decent screens.

I really appreciate you making this open. I've been wanting a physical calculator on my desk for years. Any decent RPN calc is worth hundreds these days so couldn't justify that, this is exactly what I was looking for.

apoluekt, 2025-03-18:
Thanks, keep me posted how it goes, and be ready that it will require some tweaking, especially the keyboard part. I've slightly changed the design of the keycaps to remove the 3D-printed pads, and switched to the Panasonic switches with longer stems in the current version, but I haven't actually tested this myself yet.

Also have a look at https://github.com/apoluekt/OpenRPNCalc/issues/1 concerning possible issue with PCB proto service when submitting the keyboard PCB

apoluekt, 2025-04-21:
Apparently, DigiKey has a stock of Sharp screens now, although at a higher price than AliExpress. https://www.digikey.fr/en/products/detail/sharp-microelectronics/LS027B7DH01/5054066

Closed 2025-03-18.

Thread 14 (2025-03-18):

Support for DB48x

c3d, 2025-03-18:
I wonder if this would be a good platform for [DB48x](https://github.com/c3d/db48x/tree/stable), a modern implementation of RPL. At first sight, the chosen CPU is a bit small (1M of Flash, IIRC?)

Based on your experience, how difficult would it be to:
1. Add a row of keys, in order to be able to match the HP48 or HP50 keyboard layout? The schematic seems to indicate that you use all the pins on the connector, but one of them is labeled as "x".
2. Add a wide ENTER key (the thin ENTER key is considered a major downside of the HP50G)
3. Add a USB connector in addition/replacement of the ST-LINK

Just questions.

apoluekt, 2025-03-18:
I haven't looked closely to the DB48x h/w requirements, but I suspect it might require using a more powerful MCU, and possibly an external flash if it makes use of a file system. I'm considering eventually moving to the STM32U series of processors, a more performant and power-efficient option. Maybe it would make it easier for the DB48x port.

1. The connector has a couple of empty pins, so that should not be a big problem. But it will of course increase the size of the enclosure.
2. One would need to experiment with the design of this wide key. I'm not sure the current "floating" design w/o any hinges will work well.
3. Not sure the initial flashing of the empty STM32 can be done via USB.

apoluekt, 2025-03-18:
I just realised that you are in fact the author of DB48x, enchanté :) So I guess you are the best person to answer what are the minimal h/w requirements. My current CPU is identical to the one used in DM42 except that I use a smaller package with 64 pins. But the absence of external flash might be a limiting factor.

pdanek, 2025-04-02:
In your Hackday article, you mentioned you're considering new MCU for the next revision of OpenRPNCalc:
https://www.st.com/en/microcontrollers-microprocessors/stm32u5-series.html

It seems this would be more than enough for DB48X.

apoluekt, 2025-04-24:
I'm starting Rev 4 https://github.com/apoluekt/OpenRPNCalc/pull/18 which should hopefully be sufficient for DB48x

pdanek, 2025-04-24:
Awesome additions!

Does it still use CR2016 cell?

Something like CR2032 which SwissMicros uses, would almost triple the battery capacity.
For running RPL programs, battery capacity is relevant.

apoluekt, 2025-04-24:
It uses _a_ 3V coin cell, but for DB48x version, I agree that 2032 makes more sense.

jcard0na, 2025-06-30:
Hi @c3d,

I'd love to port DB48x to the OpenRPNCalc.  With that goal in mind, I have started writing a minimal OS layer for the calculator. Here you can find [the documentation](https://jcard0na.github.io/orcos/index.html) and [the code](https://github.com/jcard0na/orcos).  It is essentially a rewrite of DMCP, but my goal is not do to a full rewrite of DMCP: just enough to get db48x to run.  Would you mind taking a look at providing a bit of guidance on what should I focus on next to get DB48x up and running?

In particular, these are questions I've collected when reviewing this...

1. Does DB48x need to access the libraries stored on DM42's QSPI flash?
2. Will we be able to run it entirely from the internal flash?  (There are [ongoing discussions about using QSPI flash](https://github.com/apoluekt/OpenRPNCalc/discussions/30#discussioncomment-13554961) in this project, but I'm wondering how limiting would it be to run without it).
3. After compiling db48x for dm42, I created a new Makefile target and started to write a new shim layer `./src/orcos` following closely `./src/dmcp`.  Sounds like the right approach to start?

```
TARGET = db48x
PLATFORM = orcos
VARIANT = OpenRPNCalc
SDK = orcos/liborcos
PGM = pgm
PGM_TARGET = $(TARGET).$(PGM)
BUILD_ID = $(shell tools/build_id)

```
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

Thanks, and congratulations on your super cool project.

Javier

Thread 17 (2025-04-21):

How to contribute to this project?

jcard0na, 2025-04-21:
I love this project and I wanted to help.  There are no open "Good First Issues", nor a way to contribute.
Are you looking for help in any way?

Best,

apoluekt, 2025-04-21:
Hello Javier,

Thanks for contacting me. Do you mean mostly hardware or software contribution?

For the h/w, I think I'm close to fixing the schematics for the next revision, which will be a rather significant modification (new STM32U3 MCU, extra row of function keys, added external flash chip, and coin cell controller with supercaps). I have all the components, but haven't ordered the PCBs yet. An independent look at the schematics would be helpful.

For the software part, there is an interesting idea to try to run DB48x firmware (https://github.com/apoluekt/OpenRPNCalc/issues/14). That would require 1) the new keyboard layout and 2) a lot of work reproducing at least the minimal subset of SwissMicros [DMCP](https://technical.swissmicros.com/dmcp/) on the new hardware.

jcard0na, 2025-04-22:
Hi Anton,

I'm comfortable contributing in both areas, hardware or software, whatever is most useful to you.
Happy to review the schematics, feel free to open an issue and assign it to me when ready to review.

I suppose I would need to have hardware in order to develop software, so that can come later.

Cheers!
Javier

Closed 2025-04-22.

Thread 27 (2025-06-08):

Missing OpenRPNCalc4/Hardware/python?

stevefalco, 2025-06-08:
I'm looking at the various python scripts that place PCB components.  There is reference to appending a path:

sys.path.append("/home/poluekt/cernbox/devel/OpenRPNCalc4/Hardware/python/")

But I don't see a python directory under Hardware.  Is this provided elsewhere?  Could it be added to the repo?

Similarly, should the svg files be available somewhere?  I assume I'd need them to generate the footprints.

Closed 2025-06-09.

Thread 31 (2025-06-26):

Battery replacement slot is difficult to open

jcard0na, 2025-06-26:
Today I tried to replace the battery for the first time on my rev4 and realized the side slot is really difficult to open.
I only succeeded by pushing a paper clip through the battery screw holes just enough to get a grip point.  But not easy at all...

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

For context, we had started a conversation on battery slot redesign here:

https://github.com/apoluekt/OpenRPNCalc/discussions/22#discussioncomment-13345914

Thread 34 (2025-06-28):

Consider wiring up quad SPI lines to flash memory

jcard0na, 2025-06-28:
The Flash SPI does not [use quad SPI mode](https://github.com/apoluekt/OpenRPNCalc/blob/main/Doc/schematics.md#flash) when it probably could.  We need to analyze if the required I/O pins on the MCU can be used.

Initial discussion here:
https://github.com/apoluekt/OpenRPNCalc/discussions/30#discussioncomment-13554961

stevefalco, 2025-07-05:
I'd like to point out that QSPI DQS is not needed for the QSPI.

jcard0na, 2025-07-05:
Updating this table based on @stevefalco's revised schematic shared [here](https://github.com/apoluekt/OpenRPNCalc/issues/32#issuecomment-3039252090).

|STM32 Pin | Schematic Net Name | Notes / Function | Previous Assignment (Previous Name) |
|-- | -- | -- | --|
PA0 | kv1 |  |
PA1 | VDIV | ✅ ADC pin | PC7 (invalid: no ADC)
PA2 | kv2 | |
PA3 | F_CLK | QSPI CLK (AF10) | PA1 (F_SCLK)
PA4 | kv3 |  | PA3 |
PA5 | kv4 | | PA4 |
PA6 | F_IO3 | QSPI IO3 (AF10) | NEW ⭐
PA7 | kv5 |  | PA5
PA8 | kv6 |  |
PA9 | EXTCOMIN | LCD input |
PA10 | DISP | LCD control |
PA11 | D− | USB DM |
PA12 | D+ | USB DP |
PA13 | SWDIO | |
PA14 | SWCLK | |
PA15 | kv5 | |
PB0 | kh1 | |
PB1 | kh2 |  |
PB2 | kh3 |   |
PB3 | kh4 |   |
PB4 | kh5 |   |
PB5 | kh6 |   |
PB6 | SCL | I2C bus |
PB7 | SDA | I2C bus |
PB8 | kon | Unused |
PB10 | SCLK |   |
PB13 | kh7 |   |
PB14 | kh8 |   |
PB15 | kh9 |   |
PC0 | SCS | SPI CS, but managed in SW as a normal GPIO | |
PC1 | SI | SPI2_MOSI (AF3) |
PC2 | RDY |  |
PC3 | START | |
PC6 | USB_ON |  |
PC7 | — | Available (VDIV moved to PA1) | — |
PC8 | VSENS |  |
PC9 | — | Available | —
PC10 | F_IO0 | QSPI IO0 (AF10) | PA7 (F_SI)
PC11 | F_NCS | QSPI CS, but managed in SW as a normal GPIO | PD2 (F_CS)
PC12 | F_IO1 | QSPI IO1 (AF10) | PA6 (F_SO)
PC14 | OSC32_IN | 32kHz RTC XTAL |
PC15 | OSC32_OUT | 32kHz RTC XTAL |
PD2 | F_IO2 | QSPI IO2 (AF10) | NEW ⭐
PH0 | OSC_IN | HSE XTAL IN |
PH1 | OSC_OUT | HSE XTAL OUT |
PH3 | BOOT0 | Boot pin |
NRST | NRST | Reset pin |

@stevefalco :

1. Not needing QSPI DQS makes things easier.  I've copied your pinout verbatim for the table above.
2. Can you confirm that you are driving QSPI CS manually?  Is that preferrable over using AF10 on PA2 (OCTOSPI1_NCS)?

jcard0na, 2025-07-06:
I was looking for that under AF10 column when it was under AF5

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

I've edited the table above.  Thanks for clarifying!

apoluekt, 2025-07-06:
Thanks, great we are converging with the pinout! My only comment is that if we scrap the NBM chip as @jcard0na suggests, that would vacate quite a few pins (including also the VSENS and VDIV, since the battery voltage divider will become unnecessary). If you have any ideas what they could be used for instead, maybe we should think ahead.

jcard0na, 2025-07-06:
> I didn't know that you were thinking of scrapping the NBM chip

Discussion taking place here:  https://github.com/apoluekt/OpenRPNCalc/issues/35

> Either way, I've ordered the parts for the NBM, so I'll be able to see how well it works.

I've been trying to come up with a good test for this, but all I can think of is not very practical:  measuring battery lifetimes under different regimes is hard and time consuming.  How do you intend to evaluate the benefits of having the NBM?

stevefalco, 2025-07-07:
I haven't really thought about it yet.  I built a uCurrent clone (https://gitlab.com/stevenfalco/ucurrent) that has a scope output.  I guess I'll measure the burst behavior with and without the supercaps, and see if it levels out the surges.  I also want to measure the leakage in the supercaps, which would hurt rather than help.

jcard0na, 2025-07-07:
I see.  Profiling the current draw over time is useful, but that will not tells us the actual impact on the battery lifetime.
Battery datasheets do not provide that kind of information.  The closest I've seen is statements like "Maximum Pulse Discharge Current at 1 sec: 20 mA" ([Duracell](https://www.duracell.com/wp-content/uploads/2021/06/CR2032CH_245mAh-CS.pdf))

If these types of pulses can be supported by the battery without major impact to lifetime, we could easily enforce that in software (i.e. erasing one flash sector at a time when on battery and only allowing full chip erase when powered via USB, for instance).

At any rate, the measurements you propose are a good start.

stevefalco, 2025-07-07:
Yeah - I really have no experience with super low power systems.  That is part of what makes this project fun. There is a lot new to learn!

I sent the gerbers over to OshPark to have the boards made.  And I ordered some displays from AliExpress.  I have some from Adafruit but those are mounted on breakout boards, so while they are fine for experimenting I cannot use them for the calculator without a lot of mechanical mischief.

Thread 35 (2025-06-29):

NBM5100A inductor should have sufficient saturation current

apoluekt, 2025-06-29:
As per the NBM5100A datasheet, the L5 inductor should have a saturation current of at least 1A. There are no such inductors in the 0805 package, so the footprint on the PCB needs to be changed. Discussion is here: https://github.com/apoluekt/OpenRPNCalc/discussions/30

apoluekt, 2025-07-06:
You are maybe right that using the NBM chip in our case is kind of overengineering. I was mostly considering CR2016 power when I thought some buffer would be needed, but with 2032, I agree that if the spikes are maximum 10 mA even in high-performance flash mode, we can get away without it. Assuming, of course, we use Macronix flash and not the more hungry chips.

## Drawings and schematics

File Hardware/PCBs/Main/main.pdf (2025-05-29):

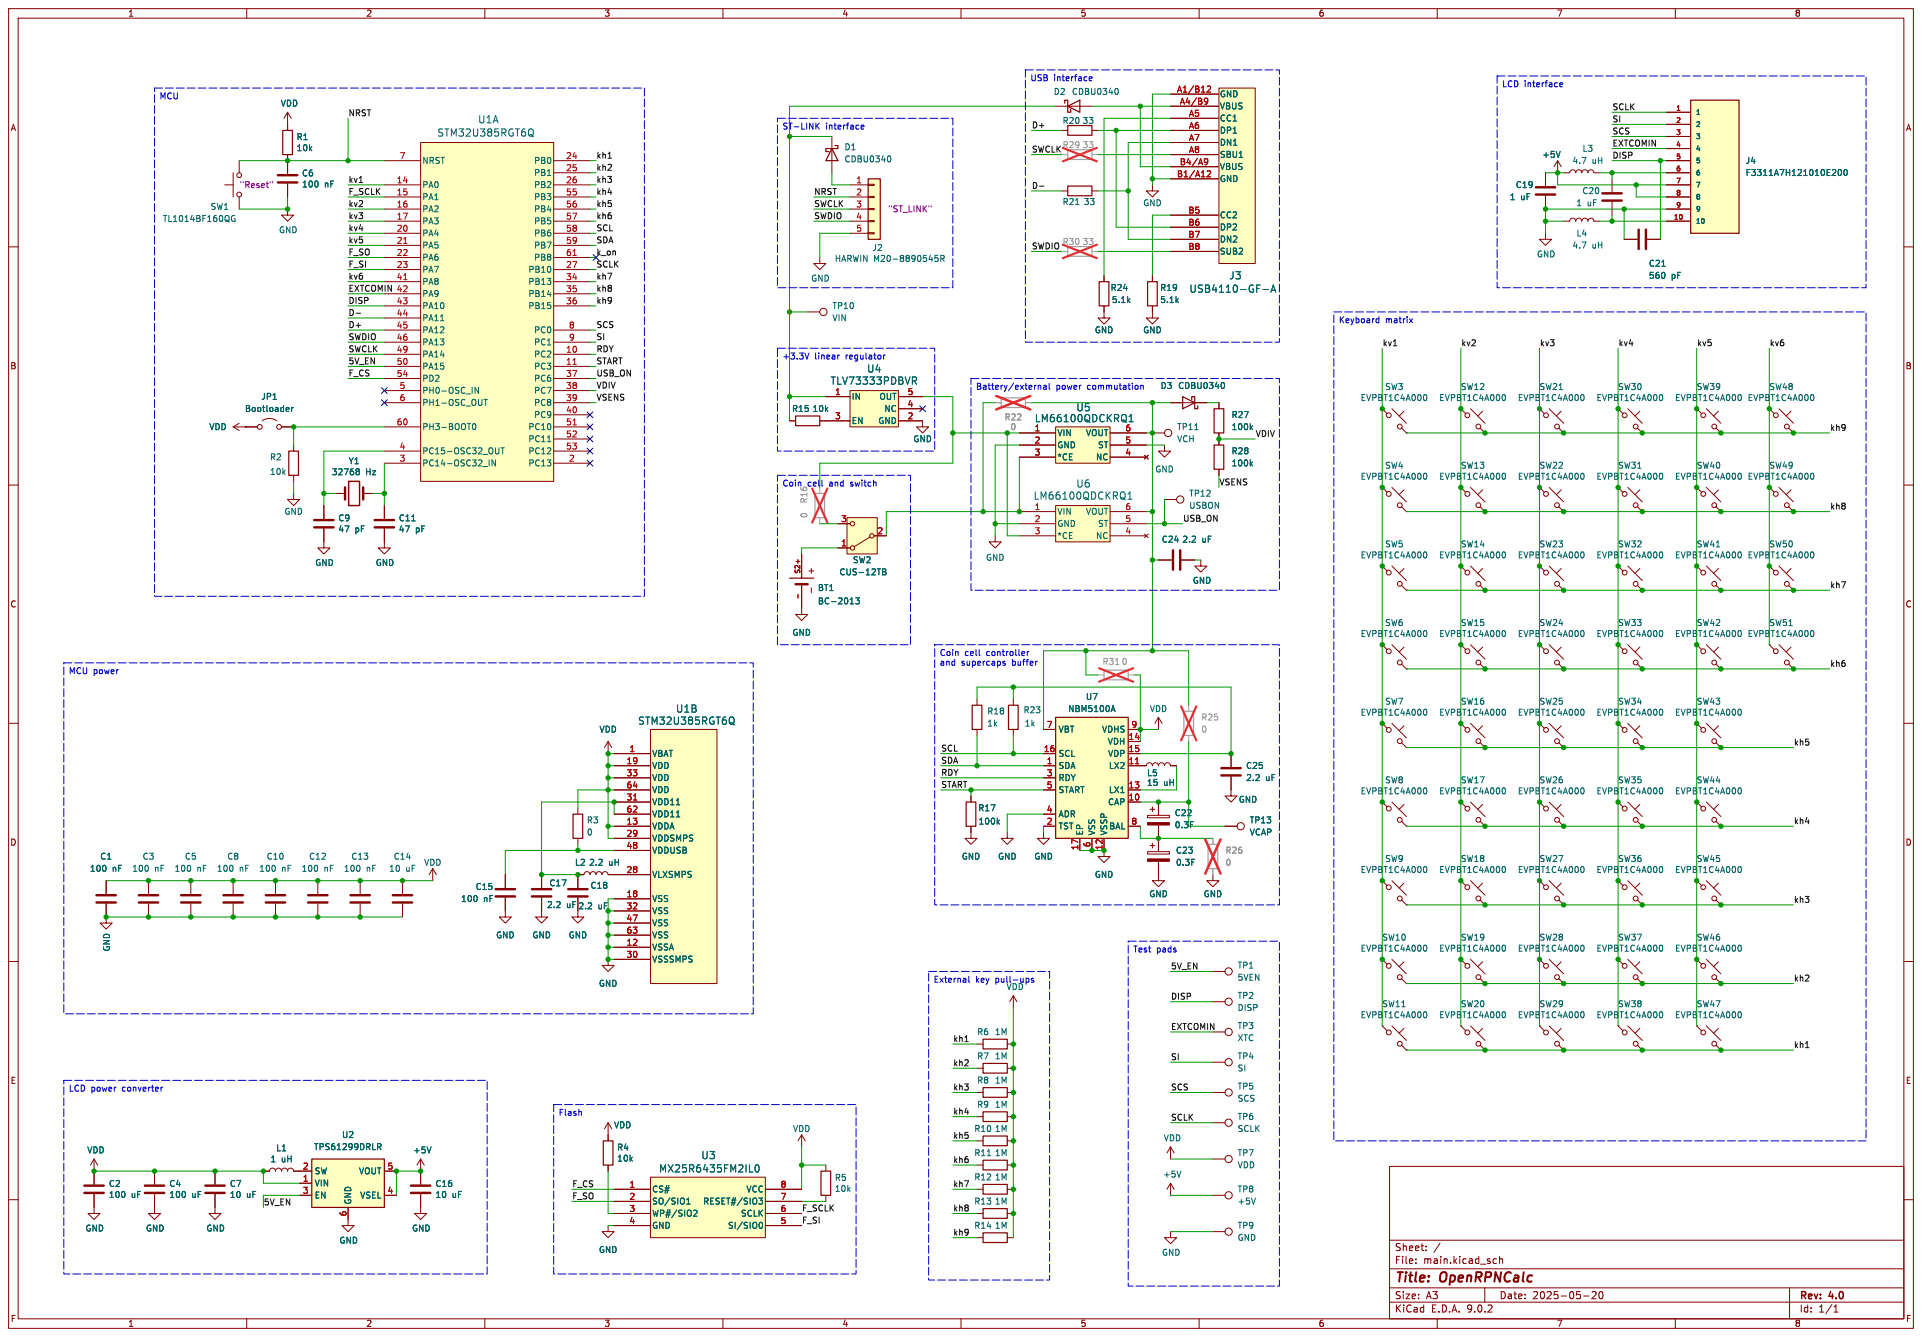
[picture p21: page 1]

6 VSSP 12 VDHS 9 VDH 14 VDP 15

kh2 START SCL SDA RDY

External key pull-ups

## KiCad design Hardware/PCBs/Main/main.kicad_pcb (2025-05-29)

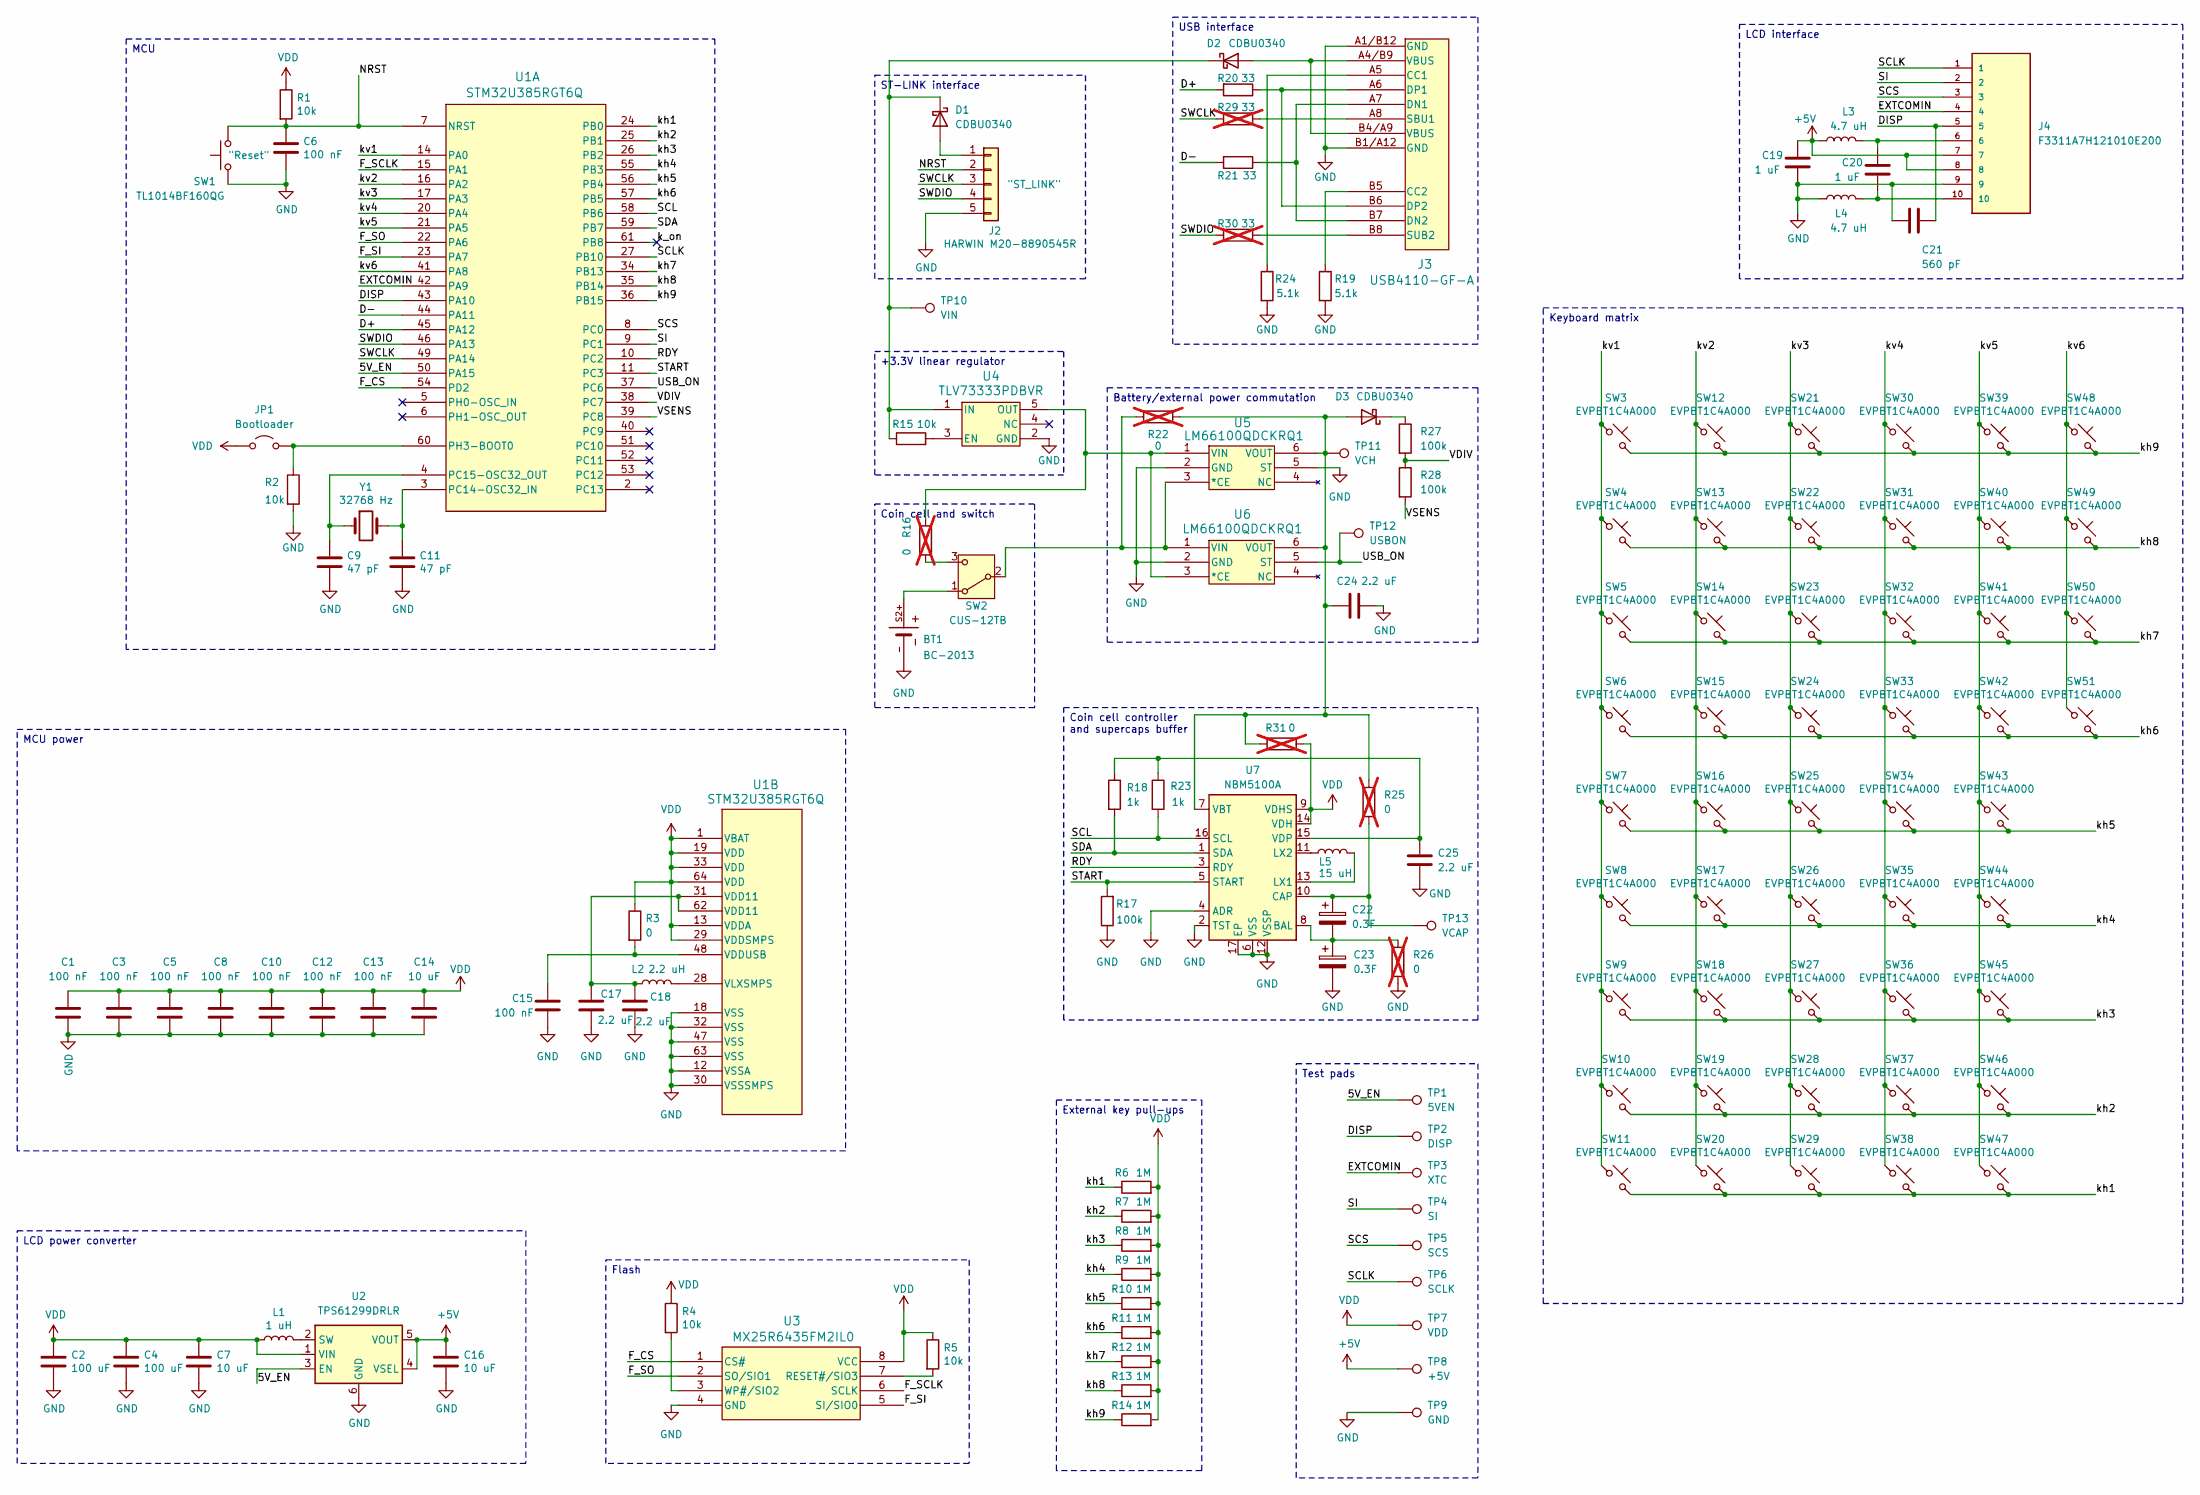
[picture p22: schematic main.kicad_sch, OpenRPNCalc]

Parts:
BT1: BC-2013; BAT_BC-2013; PARTREV D
C1, C3, C5, C6, C8, C10, C12, C13, C15: 100 nF; C_0603_1608Metric_Pad1.08x0.95mm_HandSolder
C2, C4: 100 uF; C_0805_2012Metric_Pad1.18x1.45mm_HandSolder
C7, C14, C16: 10 uF; C_0603_1608Metric_Pad1.08x0.95mm_HandSolder
C9, C11: 47 pF; C_0603_1608Metric_Pad1.08x0.95mm_HandSolder
C17, C18, C24, C25: 2.2 uF; C_0603_1608Metric_Pad1.08x0.95mm_HandSolder
C19, C20: 1 uF; C_0603_1608Metric_Pad1.08x0.95mm_HandSolder
C21: 560 pF; C_0603_1608Metric_Pad1.08x0.95mm_HandSolder
C22, C23: 0.3F; Supercap_4x10
D1, D2, D3: CDBU0340; D_0603_1608Metric_Pad1.05x0.95mm_HandSolder
J2: HARWIN M20-8890545R; HARWIN_M20-8890545R
J3: USB4110-GF-A; GCT_USB4110GFA
J4: F3311A7H121010E200; AMPHENOL_F3311A7H121010E200; PARTREV A
JP1: Bootloader; R_0603_1608Metric_Pad0.98x0.95mm_HandSolder
L1: 1 uH; L_0805_2012Metric_Pad1.15x1.40mm_HandSolder
L2: 2.2 uH; L_0805_2012Metric_Pad1.05x1.20mm_HandSolder
L3, L4: 4.7 uH; L_0805_2012Metric_Pad1.15x1.40mm_HandSolder
L5: 15 uH; L_0805_2012Metric_Pad1.05x1.20mm_HandSolder
R1, R2, R4, R5, R15: 10k; R_0603_1608Metric_Pad0.98x0.95mm_HandSolder
R3: 0; R_0603_1608Metric_Pad0.98x0.95mm_HandSolder
R6, R7, R8, R9, R10, R11, R12, R13, R14: 1M; R_0603_1608Metric_Pad0.98x0.95mm_HandSolder
R16, R22, R25, R26, R31: 0; R_0603_1608Metric_Pad0.98x0.95mm_HandSolder; not fitted
R17, R27, R28: 100k; R_0603_1608Metric_Pad0.98x0.95mm_HandSolder
R18, R23: 1k; R_0603_1608Metric_Pad0.98x0.95mm_HandSolder
R19, R24: 5.1k; R_0603_1608Metric_Pad0.98x0.95mm_HandSolder
R20, R21: 33; R_0603_1608Metric_Pad0.98x0.95mm_HandSolder
R29, R30: 33; R_0603_1608Metric_Pad0.98x0.95mm_HandSolder; not fitted
SW1: TL1014BF160QG; TL1014BF160QG_EWI
SW2: CUS-12TB; CUS-12TB_NDC
SW3, SW4, SW5, SW6, SW7, SW8, SW9, SW10, SW11, SW12, SW13, SW14, SW15, SW16, SW17, SW18, SW19, SW20, SW21, SW22, SW23, SW24, SW25, SW26, SW27, SW28, SW29, SW30, SW31, SW32, SW33, SW34, SW35, SW36, SW37, SW38, SW39, SW40, SW41, SW42, SW43, SW44, SW45, SW46, SW47, SW48, SW49, SW50, SW51: EVPBT1C4A000; SW_SPST_EVQQ2
TP1: 5VEN; TestPoint_Pad_D2.0mm
TP2: DISP; TestPoint_Pad_D2.0mm
TP3: XTC; TestPoint_Pad_D2.0mm
TP4: SI; TestPoint_Pad_D2.0mm
TP5: SCS; TestPoint_Pad_D2.0mm
TP6: SCLK; TestPoint_Pad_D2.0mm
TP7: VDD; TestPoint_Pad_D2.0mm
TP8: +5V; TestPoint_Pad_D2.0mm
TP9: GND; TestPoint_Pad_D2.0mm
TP10: VIN; TestPoint_Pad_D2.0mm
TP11: VCH; TestPoint_Pad_D2.0mm
TP12: USBON; TestPoint_Pad_D2.0mm
TP13: VCAP; TestPoint_Pad_D2.0mm
U1: STM32U385RGT6Q; LQFP64_STM
U2: TPS61299DRLR; SOT-563
U3: MX25R6435FM2IL0; SOP_8L_200_MAC
U4: TLV73333PDBVR; DBV0005A_N
U5, U6: LM66100QDCKRQ1; SC70-6_DCK_TEX
U7: NBM5100A; DHVQFN-16-1EP_2.5x3.5mm_P0.5mm_EP1x2mm
Y1: 32768 Hz; Crystal_SMD_2012-2Pin_2.0x1.2mm_HandSoldering

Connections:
+5V: C16.1, C19.1, J4.7, J4.8, L3.1, TP8.1, U2.4 (VSEL), U2.5 (VOUT)
/5V_EN: TP1.1, U1.50 (PA15), U2.3 (EN)
/D+: R20.2, U1.45 (PA12)
/D-: R21.2, U1.44 (PA11)
/DISP: C21.1, J4.5, TP2.1, U1.43 (PA10)
/EXTCOMIN: J4.4, TP3.1, U1.42 (PA9)
/F_CS: U1.54 (PD2), U3.1 (CS#)
/F_SCLK: U1.15 (PA1), U3.6 (SCLK)
/F_SI: U1.23 (PA7), U3.5 (SI/SIO0)
/F_SO: U1.22 (PA6), U3.2 (SO/SIO1)
/NRST: C6.1, J2.2, R1.2, SW1.1, U1.7 (NRST)
/RDY: U1.10 (PC2), U7.3 (RDY)
/SCL: R23.2, U1.58 (PB6), U7.16 (SCL)
/SCLK: J4.1, TP6.1, U1.27 (PB10)
/SCS: J4.3, TP5.1, U1.8 (PC0)
/SDA: R18.2, U1.59 (PB7), U7.1 (SDA)
/SI: J4.2, TP4.1, U1.9 (PC1)
/START: R17.2, U1.11 (PC3), U7.5 (START)
/SWCLK: J2.3, R29.2, U1.49 (PA14)
/SWDIO: J2.4, R30.2, U1.46 (PA13)
/USB_ON: TP12.1, U1.37 (PC6), U6.5 (ST)
/VDIV: R27.2, R28.1, U1.38 (PC7)
/VSENS: R28.2, U1.39 (PC8)
/k_on: U1.61 (PB8)
/kh1: R6.1, SW11.2, SW20.2, SW29.2, SW38.2, SW47.2, U1.24 (PB0)
/kh2: R7.1, SW10.2, SW19.2, SW28.2, SW37.2, SW46.2, U1.25 (PB1)
/kh3: R8.1, SW9.2, SW18.2, SW27.2, SW36.2, SW45.2, U1.26 (PB2)
/kh4: R9.1, SW8.2, SW17.2, SW26.2, SW35.2, SW44.2, U1.55 (PB3)
/kh5: R10.1, SW7.2, SW16.2, SW25.2, SW34.2, SW43.2, U1.56 (PB4)
/kh6: R11.1, SW6.2, SW15.2, SW24.2, SW33.2, SW42.2, SW51.2, U1.57 (PB5)
/kh7: R12.1, SW5.2, SW14.2, SW23.2, SW32.2, SW41.2, SW50.2, U1.34 (PB13)
/kh8: R13.1, SW4.2, SW13.2, SW22.2, SW31.2, SW40.2, SW49.2, U1.35 (PB14)
/kh9: R14.1, SW3.2, SW12.2, SW21.2, SW30.2, SW39.2, SW48.2, U1.36 (PB15)
/kv1: SW3.1, SW4.1, SW5.1, SW6.1, SW7.1, SW8.1, SW9.1, SW10.1, SW11.1, U1.14 (PA0)
/kv2: SW12.1, SW13.1, SW14.1, SW15.1, SW16.1, SW17.1, SW18.1, SW19.1, SW20.1, U1.16 (PA2)
/kv3: SW21.1, SW22.1, SW23.1, SW24.1, SW25.1, SW26.1, SW27.1, SW28.1, SW29.1, U1.17 (PA3)
/kv4: SW30.1, SW31.1, SW32.1, SW33.1, SW34.1, SW35.1, SW36.1, SW37.1, SW38.1, U1.20 (PA4)
/kv5: SW39.1, SW40.1, SW41.1, SW42.1, SW43.1, SW44.1, SW45.1, SW46.1, SW47.1, U1.21 (PA5)
/kv6: SW48.1, SW49.1, SW50.1, SW51.1, U1.41 (PA8)
GND: BT1.-, C1.1, C2.2, C3.1, C4.2, C5.1, C6.2, C7.2, C8.1, C9.2, C10.1, C11.2, C12.1, C13.1, C14.1, C15.2, C16.2, C17.2, C18.2, C19.2, C21.2, C23.2, C24.2, C25.2, J2.5, J3.A1/B12 (GND), J3.B1/A12 (GND), J4.9, L4.1, R2.2, R17.1, R19.2, R24.2, R26.2, SW1.2, TP9.1, U1.12 (VSSA), U1.18 (VSS), U1.30 (VSSSMPS), U1.32 (VSS), U1.47 (VSS), U1.63 (VSS), U2.6 (GND), U3.4 (GND), U4.2 (GND), U5.2 (GND), U5.5 (ST), U6.2 (GND), U7.2 (TST), U7.4 (ADR), U7.6 (VSS), U7.12 (VSSP), U7.17 (EP)
unnamed: C17.1, C18.1, L2.1, U1.31 (VDD11), U1.62 (VDD11)
unnamed: C20.1, J4.6, L3.2
unnamed: C20.2, J4.10, L4.2
unnamed: D1.2 (A), J2.1
unnamed: D1.1 (K), D2.1 (K), R15.1, TP10.1, U4.1 (IN)
unnamed: D2.2 (A), J3.A4/B9 (VBUS), J3.B4/A9 (VBUS)
unnamed: C24.1, D3.2 (A), R22.1, R25.1, R31.1, TP11.1, U5.6 (VOUT), U6.6 (VOUT), U7.7 (VBT)
unnamed: D3.1 (K), R27.1
unnamed: J3.A5 (CC1), R24.1
unnamed: J3.B5 (CC2), R19.1
unnamed: J3.A7 (DN1), J3.B7 (DN2), R21.1
unnamed: J3.A6 (DP1), J3.B6 (DP2), R20.1
unnamed: J3.A8 (SBU1), R29.1
unnamed: J3.B8 (SUB2), R30.1
unnamed: JP1.2 (B), R2.1, U1.60 (PH3-BOOT0)
unnamed: BT1.S2+, SW2.1 (A)
unnamed: R22.2, SW2.2 (B), U5.3 (*CE), U6.1 (VIN)
unnamed: R16.1, SW2.3 (C)
unnamed: C11.1, U1.3 (PC14-OSC32_IN), Y1.2
unnamed: C9.1, U1.4 (PC15-OSC32_OUT), Y1.1
unnamed: C15.1, R3.2, U1.48 (VDDUSB)
unnamed: L2.2, U1.28 (VLXSMPS)
unnamed: L1.2, U2.2 (SW)
unnamed: R5.2, U3.7 (RESET#/SIO3)
unnamed: R4.2, U3.3 (WP#/SIO2)
unnamed: R15.2, U4.3 (EN)
unnamed: R16.2, U4.5 (OUT), U5.1 (VIN), U6.3 (*CE)
unnamed: C22.2, C23.1, R26.1, U7.8 (BAL)
unnamed: C22.1, R25.2, TP13.1, U7.10 (CAP)
unnamed: L5.2, U7.13 (LX1)
unnamed: L5.1, U7.11 (LX2)
unnamed: C25.1, R18.1, R23.1, U7.15 (VDP)
VDD: C1.2, C2.1, C3.2, C4.1, C5.2, C7.1, C8.2, C10.2, C12.2, C13.2, C14.2, JP1.1 (A), L1.1, R1.1, R3.1, R4.1, R5.1, R6.2, R7.2, R8.2, R9.2, R10.2, R11.2, R12.2, R13.2, R14.2, R31.2, TP7.1, U1.1 (VBAT), U1.13 (VDDA), U1.19 (VDD), U1.29 (VDDSMPS), U1.33 (VDD), U1.64 (VDD), U2.1 (VIN), U3.8 (VCC), U7.9 (VDHS), U7.14 (VDH)

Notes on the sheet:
MCU
Keyboard matrix
+3.3V linear regulator
Flash
LCD interface
MCU power
Battery/external power commutation
Coin cell controller and supercaps buffer
Coin cell and switch
ST-LINK interface
Test pads
LCD power converter
USB interface
External key pull-ups

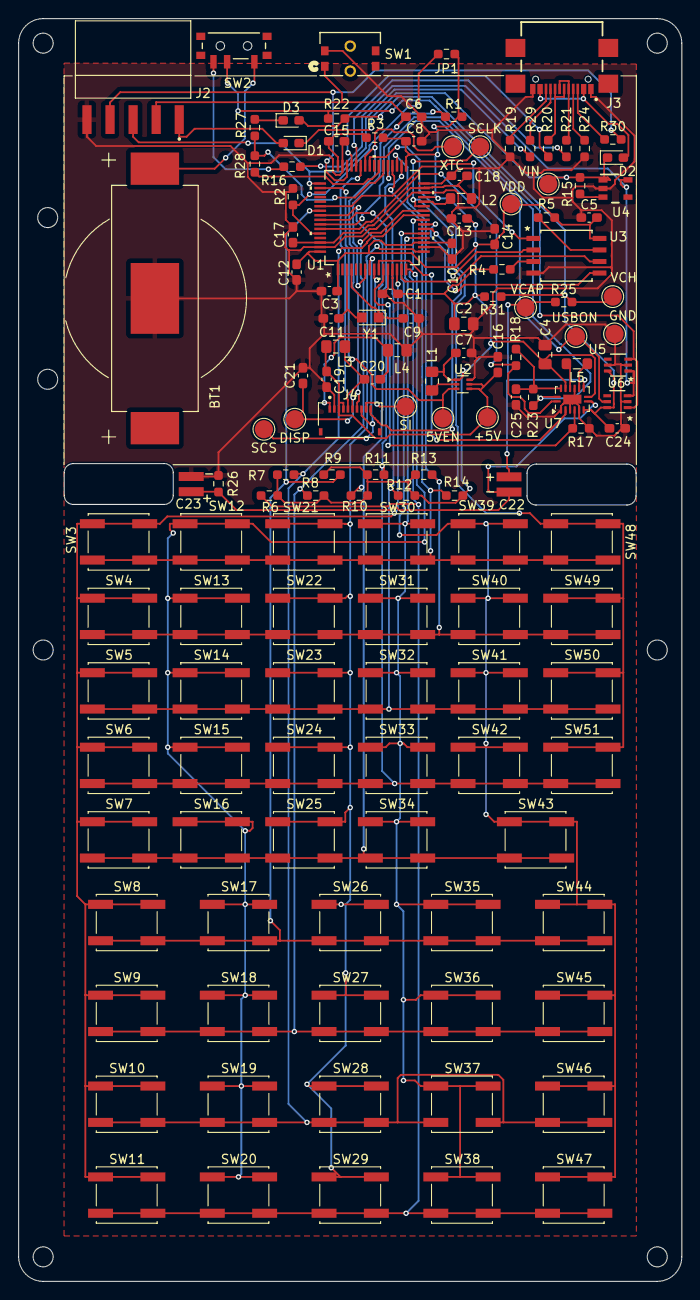
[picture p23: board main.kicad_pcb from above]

Board: 2 copper layers, 73.0 x 139.0 mm, 141 parts (0 on the bottom side), 72 nets.

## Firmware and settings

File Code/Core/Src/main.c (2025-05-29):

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
/* Includes ------------------------------------------------------------------*/
#include "main.h"

/* USER CODE BEGIN Includes */
#include <stdio.h>
#include "string.h"
#include "fonts.h"
#include "sharp.h"
#include "calc.h"
#include "io.h"
/* USER CODE END Includes */

/* USER CODE BEGIN PD */

#define NUM_COLUMN_PINS 6
#define NUM_ROW_PINS 9

#define OFF_TIMEOUT (5*120) // 5 min timeout before switching off

/* USER CODE END PD */

ADC_HandleTypeDef hadc1;

LPTIM_HandleTypeDef hlptim1;

SPI_HandleTypeDef hspi2;

TIM_HandleTypeDef htim1;

/* USER CODE BEGIN PV */

int off;
int timeout_counter;

const uint16_t row_pin_array[NUM_ROW_PINS] = {
		GPIO_PIN_0, GPIO_PIN_1, GPIO_PIN_2, GPIO_PIN_3,
		GPIO_PIN_4, GPIO_PIN_5, GPIO_PIN_13, GPIO_PIN_14, GPIO_PIN_15};

const uint16_t column_pin_array[NUM_COLUMN_PINS] = {
		GPIO_PIN_0, GPIO_PIN_2, GPIO_PIN_3,
		GPIO_PIN_4, GPIO_PIN_5, GPIO_PIN_8};

/* USER CODE END PV */

void SystemClock_Config(void);
static void MX_GPIO_Init(void);
static void MX_ICACHE_Init(void);
static void MX_LPTIM1_Init(void);
static void MX_TIM1_Init(void);
static void MX_SPI2_Init(void);
static void MX_ADC1_Init(void);
/* USER CODE BEGIN 0 */

// Switch input pins back to interrupt mode
// and put STM to STOP
void put_to_sleep() {
	GPIO_InitTypeDef GPIO_InitStruct = {0};

	if (off) {
		// Only set the row pin corresponding to ON/OFF key to ext. interrupt mode
		GPIO_InitStruct.Pin = GPIO_PIN_15;
		GPIO_InitStruct.Pull = GPIO_PULLUP; // Use external 1M pull-up to minimise current draw
		GPIO_InitStruct.Mode = GPIO_MODE_IT_RISING_FALLING;
		HAL_GPIO_Init(GPIOB, &GPIO_InitStruct);

		GPIO_InitStruct.Pin = GPIO_PIN_0|GPIO_PIN_1|GPIO_PIN_2|GPIO_PIN_3
				|GPIO_PIN_4|GPIO_PIN_5|GPIO_PIN_13|GPIO_PIN_14;
		GPIO_InitStruct.Mode = GPIO_MODE_INPUT;
		GPIO_InitStruct.Pull = GPIO_PULLUP; // Use external 1M pull-up to minimise current draw
		HAL_GPIO_Init(GPIOB, &GPIO_InitStruct);
	} else {
		GPIO_InitStruct.Pin = GPIO_PIN_0|GPIO_PIN_1|GPIO_PIN_2|GPIO_PIN_3
				|GPIO_PIN_4|GPIO_PIN_5|GPIO_PIN_13|GPIO_PIN_14|GPIO_PIN_15;
		GPIO_InitStruct.Pull = GPIO_PULLUP;
		GPIO_InitStruct.Mode = GPIO_MODE_IT_RISING_FALLING;
		HAL_GPIO_Init(GPIOB, &GPIO_InitStruct);
	}
	// Delay 100 us for all transitional processes to finish
	// e.g. OD pins with external pull-ups take a long time to change state
	delay_us(100);

	HAL_PWR_EnableSleepOnExit();
	HAL_SuspendTick();
	HAL_PWR_EnterSTOPMode(PWR_LOWPOWERMODE_STOP2, PWR_STOPENTRY_WFI);
}

// Switch input pins to simple "INPUT" mode (no interrupt)
// Called after waking up for keyboard matrix scan
// Internal pull-up is enabled for faster response
void switch_input() {
	GPIO_InitTypeDef GPIO_InitStruct = {0};

	GPIO_InitStruct.Pin = GPIO_PIN_0|GPIO_PIN_1|GPIO_PIN_2|GPIO_PIN_3
			|GPIO_PIN_4|GPIO_PIN_5|GPIO_PIN_13|GPIO_PIN_14|GPIO_PIN_15;
	GPIO_InitStruct.Mode = GPIO_MODE_INPUT;
	GPIO_InitStruct.Pull = GPIO_PULLUP;
	HAL_GPIO_Init(GPIOB, &GPIO_InitStruct);
}

uint16_t scan_keyboard(void) {
	int16_t pressed_row = 0;
	int16_t pressed_column = -1;
	uint16_t multiple_key_press = 0;

	// Set all output column pins to high
	for (uint16_t column = 0; column < NUM_COLUMN_PINS; column++) {
		HAL_GPIO_WritePin(GPIOA, column_pin_array[column], GPIO_PIN_SET);
	}

	// Scan columns
	for (int16_t column = 0; column < NUM_COLUMN_PINS; column++) {
		HAL_GPIO_WritePin(GPIOA, column_pin_array[column], GPIO_PIN_RESET); // Set column pin to low
		delay_us(20);   // Small delay (20 us) for all transitional processes to finish

		// Read row pins
		for (int16_t row = 0; row < NUM_ROW_PINS; row++) {
			GPIO_PinState status = HAL_GPIO_ReadPin(GPIOB, row_pin_array[row]);
			if (status == GPIO_PIN_RESET) {
				if (pressed_column == -1) {
					pressed_row = row;
					pressed_column = column;
				} else {
					// Another key press already registered
					multiple_key_press = 1;
				}
			}
		}

		HAL_GPIO_WritePin(GPIOA, column_pin_array[column], GPIO_PIN_SET); // Set column pin back to high
	}

	// Reset all output column pins to low
	for (uint16_t column = 0; column < NUM_COLUMN_PINS; column++) {
		HAL_GPIO_WritePin(GPIOA, column_pin_array[column], GPIO_PIN_RESET);
	}

	if (pressed_column >= 0 && !multiple_key_press)
		// Only if single key pressed
		return (pressed_column + pressed_row*NUM_COLUMN_PINS + 1);
	else
		// Return 0 if no keys or multiple keys pressed
		return 0;
}

/* USER CODE END 0 */

/**
  * @brief  The application entry point.
  * @retval int
  */
int main(void)
{

  /* MCU Configuration--------------------------------------------------------*/

  /* Reset of all peripherals, Initializes the Flash interface and the Systick. */
  HAL_Init();

  /* USER CODE BEGIN Init */

  off = 0;
  timeout_counter = 0;

  /* USER CODE END Init */

  /* Configure the system clock */
  SystemClock_Config();

  /* USER CODE BEGIN SysInit */
  HAL_PWREx_ConfigSupply(PWR_SMPS_SUPPLY);

  /* USER CODE END SysInit */

  /* Initialize all configured peripherals */
  MX_GPIO_Init();
  MX_ICACHE_Init();
  MX_LPTIM1_Init();
  MX_TIM1_Init();
  MX_SPI2_Init();
  MX_ADC1_Init();
  /* USER CODE BEGIN 2 */

  HAL_LPTIM_TimeOut_Start_IT(&hlptim1, 8192);
  HAL_GPIO_WritePin(GPIOA, GPIO_PIN_15, GPIO_PIN_SET); // 5V booster enable

  sharp_init(&htim1, &hspi2);
  sharp_clear();

  uint16_t keycode = scan_keyboard();
  if (keycode == 49) { // RESET with "F" button pressed
	memset(buffer, 0xFF, BUFFER_SIZE);
	sharp_string("Waiting ST-LINK", &font_24x40, 10, 0);
	sharp_send_buffer(120, 40);
	HAL_Delay(30000); // Delay to connect ST-Link probe
	sharp_clear();
  }

  uint16_t last_keycode = keycode;

  calc_init();

  /* USER CODE END 2 */

  /* Infinite loop */
  /* USER CODE BEGIN WHILE */

  while (1)
  {
		uint16_t keycode = 0;
		timeout_counter = 0;

		switch_input();

		HAL_Delay(10); // Debouncing delay in ms

		keycode = scan_keyboard();

		if (keycode == 54 && off && last_keycode == 0) {  // Calculator was OFF and the ON button was pressed
			HAL_GPIO_WritePin(GPIOA, GPIO_PIN_15, GPIO_PIN_SET); // 5V booster enable
			HAL_Delay(1); // Wait while 5V rises
			HAL_GPIO_WritePin(GPIOA, GPIO_PIN_10, GPIO_PIN_SET); // DISP signal to "ON"
			delay_us(30);
			keycode = 0;
			off = 0;
			sharp_clear();
			calc_refresh();
		}
		int ret = 1;

		if (!off) {

			if (keycode) {
				ret = calc_on_key(keycode);
			}

			if (!ret) {  // OFF command received
				delay_us(30);
				HAL_GPIO_WritePin(GPIOA, GPIO_PIN_10, GPIO_PIN_RESET);  // DISP signal to "OFF"
				delay_us(30);
				HAL_GPIO_WritePin(GPIOA, GPIO_PIN_9, GPIO_PIN_RESET);   // EXTCOMIN signal of "OFF"
				HAL_GPIO_WritePin(GPIOA, GPIO_PIN_15, GPIO_PIN_RESET);  // 5V booster disable
				off = 1;
			}
		}

		last_keycode = keycode;
		put_to_sleep(off);

    /* USER CODE END WHILE */

    /* USER CODE BEGIN 3 */
  }
  /* USER CODE END 3 */
}

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
/* USER CODE BEGIN 4 */
void HAL_GPIO_EXTI_Rising_Callback(uint16_t GPIO_Pin)
{
	SystemClock_Config ();
	HAL_ResumeTick();
	HAL_PWR_DisableSleepOnExit();
}

void HAL_GPIO_EXTI_Falling_Callback(uint16_t GPIO_Pin)
{
	SystemClock_Config ();
	HAL_ResumeTick();
	HAL_PWR_DisableSleepOnExit();
}

void HAL_LPTIM_CompareMatchCallback (LPTIM_HandleTypeDef *hlptim)
{
	if (!off) {
		timeout_counter++;
		if (timeout_counter > OFF_TIMEOUT) {
			HAL_GPIO_WritePin(GPIOA, GPIO_PIN_10, GPIO_PIN_RESET);  // DISP signal to "OFF"
			HAL_GPIO_WritePin(GPIOA, GPIO_PIN_9, GPIO_PIN_RESET);   // EXTCOMIN signal of "OFF"
			HAL_GPIO_WritePin(GPIOA, GPIO_PIN_15, GPIO_PIN_RESET);  // 5V booster disable
			off = 1;
		}

		HAL_GPIO_TogglePin(GPIOA, GPIO_PIN_9);  // Toggle LCD refresh signal (EXTIN)
	}
}

/* USER CODE END 4 */
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


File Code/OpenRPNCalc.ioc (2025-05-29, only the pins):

Mcu.UserName=STM32U385RGTxQ
PA0.Signal=GPIO_Output
PA10.Signal=GPIO_Output
PA2.Signal=GPIO_Output
PA3.Signal=GPIO_Output
PA4.Signal=GPIO_Output
PA5.Signal=GPIO_Output
PA8.Signal=GPIO_Output
PA9.Signal=GPIO_Output
PB0.Signal=GPXTI0
PB1.Signal=GPXTI1
PB10.Signal=SPI2_SCK
PB13.Signal=GPXTI13
PB14.Signal=GPXTI14
PB15.Signal=GPXTI15
PB2.Signal=GPXTI2
PB5.Signal=GPXTI5
PB8.Signal=GPXTI8
PC0.Signal=GPIO_Output
PC1.Signal=SPI2_MOSI
PC2.Signal=GPIO_Input
PC3.Signal=GPIO_Input
PC6.Signal=GPIO_Input
PC7.Signal=GPIO_Output
PC8.Signal=GPIO_Analog
PD2.Signal=GPIO_Output

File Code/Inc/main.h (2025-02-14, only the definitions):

#define TMS_Pin GPIO_PIN_13
#define TMS_GPIO_Port GPIOA
#define TCK_Pin GPIO_PIN_14
#define TCK_GPIO_Port GPIOA

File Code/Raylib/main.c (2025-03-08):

#include "raylib.h"
#include <stdint.h>

#include <emscripten/emscripten.h>

#include "calc.h"
#include "sharp.h"

#define SCREEN_WIDTH 490
#define SCREEN_HEIGHT 901

int keymap[49] = {
  0,  // 0
  KEY_ZERO, // 1 
  KEY_GRAVE,  // 2
  KEY_PERIOD,  // 3
  KEY_U, // 4
  KEY_ENTER, // 5
  0, // 6
  KEY_ONE, // 7
  KEY_TWO, // 8
  KEY_THREE, // 9 
  KEY_EQUAL, // 10
  KEY_MINUS, // 11
  0, // 12 
  KEY_FOUR, // 13
  KEY_FIVE, // 14
  KEY_SIX, // 15
  KEY_BACKSLASH, // 16
  KEY_SLASH, // 17
  0, // 18 
  KEY_SEVEN, // 19
  KEY_EIGHT, // 20
  KEY_NINE, // 21
  KEY_X, // 22 
  KEY_BACKSPACE, // 23
  0, // 24
  KEY_Q, // 25 
  KEY_I, // 26
  KEY_R, // 27
  KEY_P, // 28
  KEY_G, // 29
  KEY_Z, // 30 
  KEY_W, // 31
  KEY_N, // 32
  KEY_D, // 33
  KEY_S, // 34
  KEY_C, // 35
  KEY_T, // 36
  KEY_SPACE, // 37 
  KEY_TAB, // 38
  KEY_SEMICOLON, // 39
  KEY_M, // 40
  KEY_LEFT_BRACKET, // 41
  KEY_RIGHT_BRACKET, // 42
  KEY_LEFT_SHIFT, // 43
  KEY_LEFT_CONTROL, // 44
  KEY_F5, // 45
  KEY_F6, // 46
  KEY_F7, // 47
  KEY_F8, // 48
};

Texture2D texture; 
int block; 

int keycode_from_xy(int x, int y) {
  int large_y[4] = {
    814, 750, 681, 616
  }; 
  int large_x[5] = {
    42, 124, 207, 290, 371
  }; 
  int small_y[4] = {
    553, 491, 429, 368
  }; 
  int small_x[6] = {
    43, 110, 179, 246, 316, 385
  }; 
  for (int i=0; i<4; i++) {
    if (y>=large_y[i] && y<= large_y[i] + 44) {
      for (int j=0; j<5; j++) {
        if (x>=large_x[j] && x<=large_x[j] + 73) {
          return i*6 + j + 1; 
        }
      }
    }
  }
  for (int i=0; i<4; i++) {
    if (y>=small_y[i] && y<= small_y[i] + 39) {
      for (int j=0; j<6; j++) {
        if (x>=small_x[j] && x<=small_x[j] + 62) {
          return i*6 + j + 25; 
        }
      }
    }
  }
  return 0; 
}

void UpdateDrawFrame(void)
{
  if (!block && IsMouseButtonDown(MOUSE_BUTTON_LEFT)) {
    Vector2 position = GetMousePosition(); 
    int code = keycode_from_xy(position.x, position.y); 
    if (code) {
      calc_on_key(code); 
      BeginDrawing();
      ClearBackground(RAYWHITE);
      DrawTexture(texture, 0, 0, WHITE);
      draw_screen(45, 58); 
      EndDrawing();
      block = 1; 
    }
  }
  if (IsMouseButtonUp(MOUSE_BUTTON_LEFT)) block = 0; 
  int key = GetKeyPressed(); 
  for (int i=0; i<49; i++) {
    int code = keymap[i]; 
    if (code && key == code) {
      calc_on_key(i); 
      BeginDrawing();
      ClearBackground(RAYWHITE);
      DrawTexture(texture, 0, 0, WHITE);
      draw_screen(45, 58); 
      EndDrawing();
    }
  }
}

int main(void)
{
    InitWindow(SCREEN_WIDTH, SCREEN_HEIGHT, "basic window");

    Image image = LoadImage("resources/panel.png");
    texture = LoadTextureFromImage(image);
    UnloadImage(image);

    SetTargetFPS(20);
    BeginDrawing();
    report_voltage(2990); 
    sharp_clear(); 
    calc_init(); 
    ClearBackground(RAYWHITE);
    DrawTexture(texture, 0, 0, WHITE);
    draw_screen(45, 58); 
    EndDrawing();
    block = 0; 
    emscripten_set_main_loop(UpdateDrawFrame, 0, 1);
    CloseWindow();
    return 0;
}

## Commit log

2021-05-23 Add schematic in PNG and PDF
2021-05-28 Update stickers; Add functions for relativistic kinematics
2021-06-19 Fix schematic to fit the one actually implemented
    [calc.sch]
2021-06-25 ROT-Up and ROT-Down; Uncertainties for power and root
2025-01-01 Rev. 2
    [OpenRPNCalc.scad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]
2025-01-01 Add KiCAD images
2025-02-01 Update PCB 3D models
    [calc_v2.kicad_pcb]
2025-02-01 Add gerbers
    [calc_v2.kicad_pcb_bom.csv, calc_v2.kicad_pcb_positions.csv, calc_v2.kicad_sch]
2025-02-01 Add OpenSCAD files
    [back_lid.scad, back_lid.stl, spacer.scad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]
2025-02-01 Add schematic png
2025-02-01 Add images of 3D printed parts
2025-02-14 Add functions; keyboard scan bugfixes
    [OpenRPNCalc.ioc, main.c, main.h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]
2025-03-07 rev 3
    [back_lid.scad, back_lid.stl, calc_v2.kicad_pcb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]
2025-03-08 Update to rev 3.1
    [OpenRPNCalc_MCU.csv, OpenRPNCalc_MCU.kicad_pcb, OpenRPNCalc_MCU.kicad_pcb_bom.csv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]
2025-03-28 Rev 3.1
    [OpenRPNCalc_front_panel.kicad_pcb]
2025-04-24 Rev 4 schematics
    [OpenRPNCalc_MCU.csv, OpenRPNCalc_MCU.kicad_pcb, OpenRPNCalc_MCU.kicad_sch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]
2025-04-25 Update rev 4 schematics
    [main.kicad_pcb, main.kicad_sch]
2025-04-27 Update component names in schematic, add PDBs
    [BackPanel.kicad_pcb, EnterPad.kicad_pcb, EnterStab.kicad_pcb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]
2025-04-27 Minor schematic cleanup
    [main.kicad_sch]
2025-04-30 Production files
    [KeyTops_production.kicad_pcb, main.kicad_pcb_bom.csv, main.kicad_pcb_positions.csv]
2025-05-03 Update enter stab; add new renders
    [EnterStab.kicad_pcb]
2025-05-06 Update battery holder part name
    [main.kicad_pcb, main.kicad_sch]
2025-05-07 Update schematics.md: add BOM
2025-05-07 Update production files
    [main.kicad_pcb_bom.csv, main.kicad_pcb_positions.csv]
2025-05-20 Bugfix 4.0; added HP48 layout
    [FrontPanel_labelled_hp48.kicad_pcb, KeyTops_labelled_hp48.kicad_pcb, KeyTops_production_hp48.kicad_pcb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]

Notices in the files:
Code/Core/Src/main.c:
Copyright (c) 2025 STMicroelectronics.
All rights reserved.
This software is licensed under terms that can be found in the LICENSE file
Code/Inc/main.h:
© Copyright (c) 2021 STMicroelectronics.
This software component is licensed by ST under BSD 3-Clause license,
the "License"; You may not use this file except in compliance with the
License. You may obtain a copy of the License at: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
